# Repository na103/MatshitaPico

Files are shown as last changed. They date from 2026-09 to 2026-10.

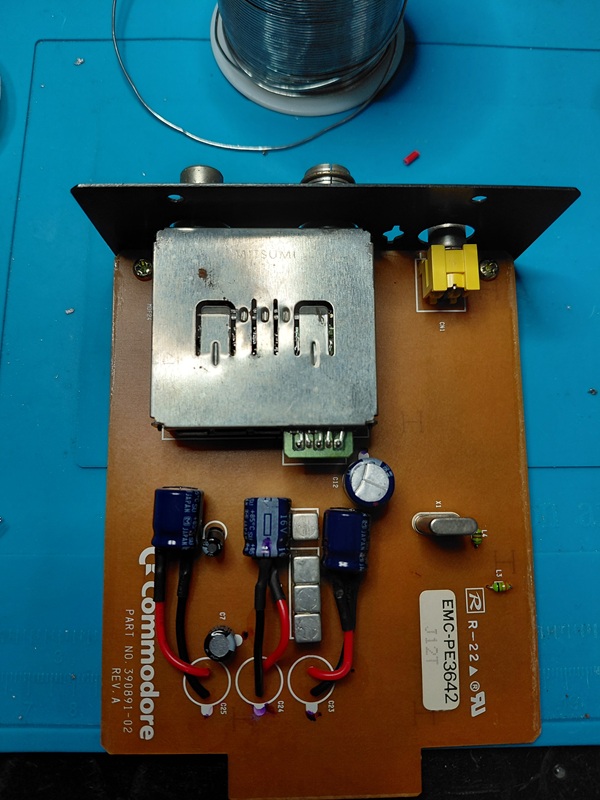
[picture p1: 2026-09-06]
img/beta_assembly/04_beta_assembly.jpg

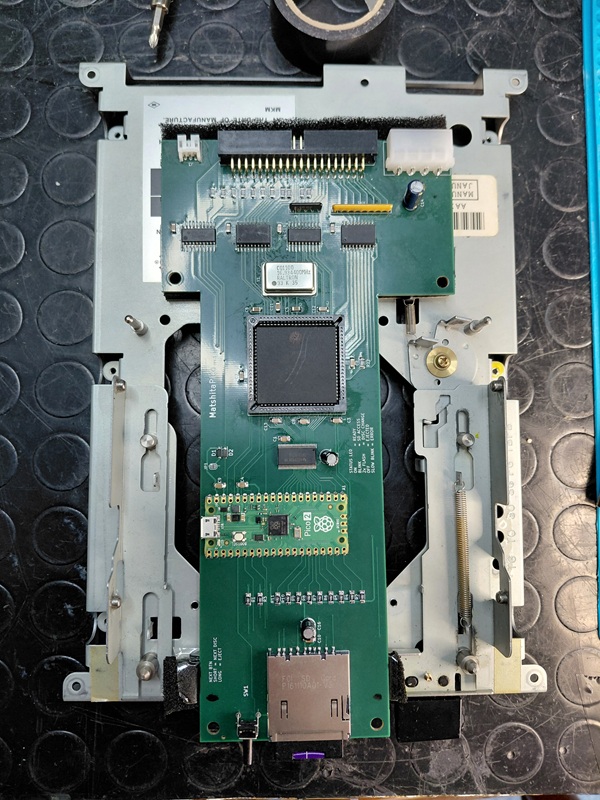
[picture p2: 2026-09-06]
img/beta_assembly/01_beta_assembly.jpg

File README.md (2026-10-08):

<!--
  MatshitaPico — Solid-state CD-ROM drive replacement for the Commodore CDTV
  Copyright (c) 2026 Nicola Avanzi (na103)
  Licensed under Creative Commons Attribution 4.0 International (CC BY 4.0).
  See LICENSE.
-->

# MatshitaPico — a solid-state CD-ROM drive for the Commodore CDTV

**MatshitaPico** is a solid-state replacement for the optical CD-ROM drive of the
**Commodore CDTV**: BIN/CUE disc images stored on a microSD
card take the place of the optical mechanism.

**Why:** many CDTV drives have a worn-out laser and cannot be repaired, and no drop-in
replacement has ever existed. This project keeps these machines alive.

> This repository contains the **CPLD design (HDL)**, **technical documentation**, **RP2350 firmware**, **KiCad hardware project of beta board** and the **Amiga-side `mpdisk.device` + boot CD builder** for hardfiles.
---

## Community beta

Because of the limited turnout in the project's closed beta testing, I have decided to open
MatshitaPico testing up to the whole Amiga community.

The final version should not differ much from this first one, apart from an ATF1508 CPLD in a
TQFP-100 package, programmable in-circuit through a JTAG connector. The key point for the final
version is the **PCB layout**: it must be designed together with a 3D-printed mounting bracket.
The original eject button could also be reused as a control button.

This first version **is** installable — as you can see from the photos [here](https://github.com/na103/MatshitaPico/tree/main/img/beta_assembly) —
but several modifications are needed to fit it. When I laid out the PCB I did not worry about
its dimensions.

## The key insight

The CDTV service manual contains **no schematic for the CD-ROM subsystem**: all of the
CD-ROM electronics (CD-DSP, the Sanyo **LC8951** decoder, the drive's own microcontroller)
live on a PCB **inside the drive mechanism**, not on the motherboard. The motherboard only
carries the *host side* — the **DMAC (U36)**, the **6525/TPI (U32)** and glue logic — which
talks to the drive through connector **CN9** (42 pins, sheet 10 of schematic #252605).

→ **CN9 is the emulation point.** The device plugs into CN9 and pretends to be the entire
drive. The LC8951 does **not** interpret commands (it is a host↔µC FIFO mailbox); the
replacement emulates both the LC8951 host interface and the drive µC command protocol
(the proprietary CDTV/Sony command set).

## Hardware architecture

```
   CDTV (CN9, 5 V TTL)
        |  DB0-7, _HWR/_HRD/_CMD/_STEN/_DTEN/DRQ/_ENABLE/_STCH + RESET
        v
   CPLD  ATF1508AS  (5 V, 128 macrocells, PLCC84, JTAG; socketed, programmed out of circuit)
        |  - real-time 5 V front-end; host-interface FSM (DRQ mode)
        |  - clock division C16M -> BCLK/LRCK; SCOR / subcode generation
        |  <- level shifting 5 V <-> 3.3 V (SN74CBTD16211 bus switch, no DIR, 5 V clamp)
        v
   MCU  RP2350 / Raspberry Pi Pico 2  (3.3 V)
        - drive command protocol - BIN/CUE from SD
        - I2S audio 44.1 kHz (PIO) - subcode Q - UI (NEXT + LED)
   + 16.9344 MHz crystal oscillator (C16M, DIP14 metal-can 5 V TTL)
```

**Key constraint:** the CN9 bus is 5 V TTL and the RP2350 is **not** 5 V-tolerant, so a
native 5 V front-end is required (**ATF1508AS**, the `AS` variant, not `ASV`). The CPLD
performs four things in parallel — master clock, I2S audio, subcode, host DMA — plus command
glue logic; the heavy protocol logic runs on the RP2350.

## What the CPLD does

The CPLD is the only chip that faces CN9 (a pure 5 V domain). It contains:

- **`clkgen`** — derives the audio clocks (`BCLK`, `LRCK`, frame sync) from the `C16M`
  master clock (16.9344 MHz = 384 x 44.1 kHz), so the audio stays phase-coherent with the
  motherboard DAC (Sanyo LC7883M).
- **`host_if`** — the LC8951-style host-interface FSM: it captures host commands (async latch
  on the rising edge of `_HWR`), drives status replies over `_HRD`/`_STEN`, and runs the DMA
  data path in **DRQ mode** (`DRQ` high = byte ready). `EOP` is not on CN9 — the DMAC counts
  it — so ending a sector is just lowering `DRQ`.
- **top level** — subcode generation (`SBCP`/`SCOR`/`EFFK`; `SCCK` is a host **input**) and
  buffering of `DATA`/`EMPHASIS` from the RP2350.

## The golden reference

`cdtv.cpp` from WinUAE (plus `cdtvcr.cpp` for the CDTV-CR variant) is a complete emulation of
the DMAC + 6525 + LC8951 + command protocol. It is the **executable specification** the
firmware is ported from. (The WinUAE sources are not redistributed here — see the WinUAE
project.) The CDTV extended ROM is the real host-side protocol engine.

## Drive command set (summary)

`0x01` seek · `0x02` read · `0x04`/`0x05` motor on/off · `0x09`/`0x0a` play LSN/MSF ·
`0x0b` play track range · `0x82` clear-error · `0x84` mode set · `0x85` mode sense ·
`0x86` capacity · `0x87` subq · `0x8a` read TOC · `0xa2`/`0xa3` front panel.

The full, byte-level command reference — including the vendor `0x6x` hardfile page — is in
[`docs/drive-commands.md`](docs/drive-commands.md).

## Status

The device is functionally complete on real hardware: data boot, persistent disc change,
CD audio (play / pause / skip / stop), CD+G graphics, and the activity LED all work on a real
CDTV. 

## Optional: hardfiles (`mpdisk.device`)

With the firmware built with `ENABLE_MPDISK`, `.hdf` hard-disk images in the root of the SD
card become read/write Amiga units **MPD0..MPD3**, served through the CD controller itself
(no extra hardware). A small boot CD loads `mpdisk.device`, mounts the hardfiles and hands the
system over to MPD0:, so a CDTV can run Workbench from a writable disk. The Amiga sources and
the boot CD builder are in [`amiga/`](amiga) and [`tools/`](tools) — see
[`amiga/README.md`](amiga/README.md).

## Thanks
Thankyou to all the people who have support this project.<br>
Andrea Quagliarini, Mirco Gaggiottini, Carlo Santagostino, Federico Di Dato.

## License

This work is licensed under the **Creative Commons Attribution 4.0 International License
(CC BY 4.0)**. See [`LICENSE`](LICENSE). You are free to share and adapt the material for any
purpose, provided you give appropriate credit.

<br><br>
If you found this my work useful, please consider buying me a cup of coffee if you want:<br>


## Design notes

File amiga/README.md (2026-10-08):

<!--
  MatshitaPico — Solid-state CD-ROM drive replacement for the Commodore CDTV
  Copyright (c) 2026 Nicola Avanzi (na103)
  Licensed under Creative Commons Attribution 4.0 International (CC BY 4.0).
  See LICENSE.
-->

# MatshitaPico — Amiga side: `mpdisk.device` and the boot CD

This directory holds the **Amiga-side sources** of the optional *mpdisk* feature:
read/write **`.hdf` hardfiles** stored on the MatshitaPico microSD and exposed to the
CDTV as block-device units **MPD0..MPD3**. The CDTV can boot from a small CD, mount
the hardfile and hand the system over to it: a CDTV with a writable hard disk, and no
extra hardware beyond the drive replacement.

The firmware half of the feature (vendor commands `0x60`–`0x64`) is compiled in only
with **`ENABLE_MPDISK`** — see [`../firmware/README.md`](../firmware/README.md) and the
byte-level reference in [`../docs/drive-commands.md`](../docs/drive-commands.md).

## How it works

```
   CDTV  (68000, Kickstart 1.3)
     |   mpdisk.device  -- trackdisk-like exec device, units MPD0..MPD3
     |       |  vendor commands on the CD command port (DMAC 0xA1)
     |       |  READ  = DMA (DRQ), like a CD sector read
     |       |  WRITE = bulk bytes on 0xA1, one block per command
     v       v
   CN9 -> CPLD -> RP2350 firmware -> FatFs -> /*.hdf on the SD card
```

There is no extra bus or connector: the device reuses the **CD controller itself**
(DMAC U36 + 6525 U32), found through `expansion.library/FindConfigDev`. The DMAC is
**shared** with the ROM-resident `cdtv.device`, which stays alive, so the pipe:

- catches the per-byte `STEN` replies with its **own INT2 server** at priority 127,
  ahead of `cdtv.device`'s (with a retry if a byte is still stolen);
- **arbitrates the DMA**: before each read chunk it checks, under `Disable()`,
  `cdtv.device`'s "CD DMA in flight" flag (`272(a6)`) and backs off if a CD transfer
  is running; the DMA itself is programmed exactly like the ROM does (`f057f4`),
  with long-word writes to `WTC`/`ACR` (byte writes are not latched by the DMAC);
- paces the 7 command bytes like the ROM does, and writes **one block per WRITE
  command**, using `STATUS` as a per-block handshake (the CPLD FIFO is 2 bytes).

## Layout

```
amiga/
├── mpdisk/                 mpdisk.device
│   ├── device.c            exec framework: romtag, init, vectors, trackdisk commands
│   ├── pipe.c / pipe.h     transport: DMAC/6525 access, STEN capture, arbitrated DMA
│   ├── pipe_stub.c         WinUAE test backend (reads work.hdf as a file, no hardware)
│   ├── mpdisk_dev.h        device base structure
│   └── Makefile            `make` -> mpdisk.device, `make stub` -> mpdisk_stub.device
├── mpmount/                mpmount: mounts MPD0..MPD3 with the geometry from the firmware
│   ├── mpmount.c           TD_GETGEOMETRY -> MakeDosNode/AddDosNode (OFS, KS 1.3 ROM)
│   ├── crt0.S              minimal entry (no utility.library on KS 1.3) + soft 32-bit div
│   └── Makefile
├── boot/
│   ├── startup-sequence    boot CD script: RMTM, mpmount, assigns to MPD0:, run its S/Startup-sequence
│   └── cd-extra/           free overlay: anything here is merged into the boot CD
└── mount/
    └── MPDisk              static Mountlist (reference / WinUAE / manual `Mount MPD0:`)
```

The PC-side tools are in [`../tools`](../tools):

| Tool | Purpose |
|---|---|
| `build-bootcd.sh` | Builds `mpdisk.device` + `mpmount`, then the boot CD (`.bin` + `.cue`). |
| `mkbootcd.py` | The CD builder: ISO9660 + CDTV trademark (or `DOS\0` bootblock) → MODE1/2352 BIN/CUE. |
| `iso2bincue.py` | EDC/ECC engine used by `mkbootcd.py`; also a standalone ISO → BIN/CUE converter. |
| `mkhdf.py` | Creates an empty `.hdf` of a given size and prints the matching Mountlist entry. |

## Build

Requirements: the **m68k-amigaos-gcc** cross compiler (Bebbo's toolchain), and
`python3` with `numpy` for the CD tools.

```sh
make -C amiga/mpdisk          # -> amiga/mpdisk/mpdisk.device
make -C amiga/mpmount         # -> amiga/mpmount/mpmount
```

### Boot CD

The boot CD needs a few **Commodore binaries** (AmigaDOS `C:` commands and the CDTV
trademark file `CDTV.TM`) which are copyrighted and **not** included. They are extracted
once from **your own genuine CDTV disc** (a MODE1/2352 `.bin`) into a git-ignored cache:

```sh
tools/build-bootcd.sh --genuine "/path/to/CDTV_genuine.bin"   # first run: extracts the cache
tools/build-bootcd.sh                                         # later runs: standalone
```

`RMTM`, `LoadWB` and `NewCLI` are not in the `/C` directory of a genuine disc: copy them
by hand into `tools/.bootcd-cache/C/` (`RMTM` from the root of the CDTV Demo Disc,
`LoadWB`/`NewCLI` from Workbench 1.3). `RMTM` must run first, or the CDTV stays on the
splash screen.

The result is `build/mpdisk-bootcd.bin` + `.cue` (or `--out <base>`): copy it into `/games`
on the SD card like any other disc.

## Preparing a hardfile

```sh
python3 tools/mkhdf.py disk0.hdf 64       # empty 64 MB hardfile
```

Copy it into the **root** of the SD card. Units are assigned to the first four `*.hdf` in
name order (`disk0.hdf`..`disk3.hdf` keeps it obvious). Format it as **OFS** (`DOS\0`,
built into the Kickstart 1.3 ROM, so no `L:FastFileSystem` is needed) — in WinUAE, mounted
as a normal hardfile, or on the CDTV. For the boot CD flow, MPD0: must contain a bootable
system (`C`, `L`, `LIBS`, `DEVS`, `S`, ...): it becomes `SYS:` and its
`S/Startup-sequence` is executed.

Use a defragmented card: a contiguous `.hdf` keeps writes away from the FAT.

## Testing in WinUAE

`make -C amiga/mpdisk stub` builds `mpdisk_stub.device`: the same `device.c` with a backend
that reads `work.hdf` as a plain file. Copy it to `DEVS:mpdisk.device`, the Mountlist to
`DEVS:`, then `Mount MPD0:`. The init result is written to `RAM:mpdisk-init.log`. This
validates the device framework without any hardware.

## Limits

- The DMAC is shared with the CD: hardfile and CD access are serialised (`Forbid()` around
  each request), and throughput is about **140 KB/s**.
- Ejecting/changing the CD still reboots the CDTV (that is `cdtv.device`'s behaviour on a
  media change), so the hardfile session ends with it.

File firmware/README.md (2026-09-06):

<!--
  MatshitaPico — Solid-state CD-ROM drive replacement for the Commodore CDTV
  Copyright (c) 2026 Nicola Avanzi (na103)
  Licensed under Creative Commons Attribution 4.0 International (CC BY 4.0).
  See LICENSE.
-->

# MatshitaPico — RP2350 firmware

This directory holds the **application source** of the RP2350 / Raspberry Pi Pico 2
firmware: the drive command protocol, BIN/CUE image handling, I2S audio, the subcode
Q / CD+G channel, and the UI (NEXT button + status LED). The CPLD design that pairs
with it (the real-time 5 V front-end on CN9) is in [`../hdl`](../hdl); the protocol
itself is documented in [`../docs`](../docs).

> This is a **read-only reference copy** of the core sources. The build system
> (`CMakeLists.txt`), the SD-card driver glue (SPI-over-PIO transport and
> `hw_config`), and the third-party FatFs library are maintained with the full
> firmware tree and are **not** included here — see *Dependencies* below.

## What runs where

```
   CDTV (CN9, 5 V TTL)
        |
        v
   CPLD  ATF1508AS   real-time front-end: host-interface FSM (DRQ mode),
        |            audio clock division (C16M -> BCLK/LRCK), subcode burst
        v            engine (SBCP/SCOR/EFFK), /INAC activity LED
   MCU  RP2350       THIS firmware: drive command protocol, SD (BIN/CUE),
                     I2S audio samples, subcode Q stream, NEXT + LED
```

The RP2350 is **not** 5 V-tolerant, so it never touches CN9 directly: the CPLD is the
only chip in the 5 V domain, and a bus switch level-shifts the CPLD↔Pico signals. The
firmware talks to the CPLD through the register/handshake contract in
[`../hdl/host_if.v`](../hdl/host_if.v) (see `src/host_link.h`).

## SD card layout

The firmware reads a FAT-formatted microSD with this layout:

```
/                 <- SD root
├── games/        <- CD-ROM images
│   ├── Game A.cue
│   ├── Game A.bin
│   ├── Game A.sub     (optional: CloneCD subchannel, enables CD+G)
│   ├── Game A.subok   (optional: empty marker, forces subcode ON for a mixed disc)
│   └── ...
├── work.hdf      <- hardfiles in the root (ENABLE_MPDISK builds only)
└── extra.hdf
```

* **CD images — `/games/*.cue`.** Discs live in the `/games/` folder as **BIN/CUE, 2352-byte
  raw** sectors (not `.iso`: an ISO is 2048-byte data only and carries no audio, sync or EDC).
  The `.cue` and its referenced `.bin` sit side by side; the NEXT button cycles through them in
  name order. A companion `.sub` (CloneCD subchannel) next to a `.cue` enables **CD+G** playback,
  and an empty `.subok` marker forces the subcode stream on for a mixed disc known to be safe.
* **Hardfiles — `*.hdf` in the root** (only when built with **`ENABLE_MPDISK`**). Amiga hard-disk
  images placed in the SD root are exposed as block-device units **MPD0..MPD3** (first four found,
  in name order). These are ordinary **`.hdf` files, interchangeable with WinUAE** — mount the same
  image in WinUAE to prepare or inspect it, then drop it in the SD root. See *Optional feature:
  mpdisk hardfiles* below.

## The golden reference

The command protocol is a port of `cdtv.cpp` from **WinUAE** (the executable
specification of the DMAC + 6525 + LC8951 + command set). The WinUAE sources are not
redistributed here. See [`../docs/drive-commands.md`](../docs/drive-commands.md) and
[`../docs/protocol-cdtv.md`](../docs/protocol-cdtv.md).

## Source layout

| File | Role |
|---|---|
| `main.cpp` | main loop: command intake, status/data replies, STCH announce, auto-insert |
| `cdtv_drive.{h,cpp}` | drive state machine + command dispatch (ported from `cdtv.cpp`) |
| `host_link.{h,cpp}` | link layer to the CPLD (IRQ capture, bus gather/scatter, handshakes) |
| `cd_image.{h,cpp}` | CD image (BIN/CUE 2352 raw): TOC, LSN→offset, prewarm, subcode gate |
| `cue_parser.{h,cpp}` | SDK-free CUE sheet parser (unit-testable on the PC) |
| `storage.{h,cpp}` | SD/FatFs glue: image scan, cached reads (data / audio / subcode) |
| `audio.{h,cpp}` | I2S-slave transmitter on A_DATA, ping-pong DMA |
| `subcode.{h,cpp}` | subcode Q + CD+G R-W stream on A_SUBQ |
| `subq_packet.h` / `subpw_block.h` | Red Book Q packet + P..W wire block builders |
| `cdrom_util.h` | LSN/MSF/BCD conversions |
| `ui.{h,cpp}` / `ui_logic.h` | NEXT button + status LED (pure logic split out for tests) |
| `pinmap.h` | RP2350 GPIO assignment (matches the routed PCB) |
| `ram_func.h` | portable macro to place critical-path code in RAM (removes XIP stalls) |
| `pio/*.pio` | PIO programs: I2S slave, subcode serialiser, SD SPI master |

Files that are compiled for both the device and the PC unit tests (`cd_image`,
`cue_parser`, `storage`, `subq_packet`, `subpw_block`, `ui_logic`) avoid the Pico SDK
in their hot paths; `ram_func.h`'s `RAM_FUNC` macro is a no-op off ARM so the shared
sources compile identically on the host.

## Dependencies (not included here)

* **Pico SDK** — the RP2350 platform (`pico/stdlib.h`, `hardware/*`, PIO tooling).
* **FatFs** (ChaN's ff15, e.g. via `no-OS-FatFS-SD-SPI-RPi-Pico`) — the FAT filesystem
  behind `storage.cpp`. Only the standard `f_*` API is used, so any FatFs port works.
* **SD driver glue** — the SPI-over-PIO transport (`sd_spi_pio`) and `hw_config` that
  bind FatFs to the rev.0 PCB pins (`pinmap.h`). The rev.0 SD pins do not map to any
  RP2350 hardware SPI, so the bus is bit-banged in PIO on `pio2`.

## Optional feature: mpdisk hardfiles

Read/write `.hdf` hard-disk images (an Amiga block device, `mpdisk.device`) are gated
behind the compile-time flag **`ENABLE_MPDISK`** (default **off**). With the flag off
the vendor pipe (commands `0x60`–`0x64`) compiles out entirely and the firmware is the
plain CD-ROM replacement; with it on, `.hdf` files in the SD root become units
MPD0..MPD3. See the `#if ENABLE_MPDISK` blocks in `cdtv_drive.cpp` / `storage.cpp` and
[`../docs/drive-commands.md`](../docs/drive-commands.md).

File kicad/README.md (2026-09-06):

## Bill of materials
| Qt. | Description | Designator | Part code | Note |
|:---:|---|---|---|---|
|4 |Res 10K |R1-R3,R22 |RC1206FR-0710KL
|6 |Res 100R |R15,R17-R21 |RC1206FR-07100RL | |
|8 |Res 47K |R4-R11 |RC1206FR-0747KL | |
|2 |Res 470R |R12, R13 |RC1206FR-07470RL | |
|2 |Res 1K |R14,R16 |RC1206FR-071KL | |
|1 |Res 0R |R23 |RC1206FR-070RL | |
|1 |Bus Array 8RES 2.2K |RN1 |4609X-101-222LF | |
|1 |Bus Array 4RES 1K |RN2 |4605X-101-102LF | |
|17 |Cap 100nF |C1-C13,C17-C20 |C1206C104K5RACTU | |
|2 |Cap 10uF |C15,C16 |EEA-GA1V100H | |
|1 |Cap 47uF |C14 |EEU-FC1V470H | |
|1 |DIODE SCHOTTKY |D1 |MBR120ESFT3G | |
|1 |DIODE SCHOTTKY |D2 |BAT54W-E3-08 | |
|1 |BUS SWITCH |U2 |SN74CBTD16211DGGR | |
|1 |CPLD ATF1508 |U1 |ATF1508AS-10JU84 | from ebay or utsource.net |
|1 |OSC DIP 16.9344MHZ  |Y1 |NA | from aliexpress | 
|1 |74LS245 |U3 |SN74LS245DWR | |
|2 |74LS244 |U4,U6 |SN74LS244DWR | |
|1 |74LS541 |U5 |SN74LS541DWR | | 
|1 |SOCKET PLCC 84POS |U1 |940-44-084-24-000000| |
|1 |PI PICO 2 RP2350 |A1 |SC1631 | |
|1 |CONN 4POS 5.08MM |J1 |641737-1 | |
|1 |CONN 40POS 2.54MM |J2 |61204021721 | |
|1 |CONN 3POS 2MM |J3 |S3B-PH-K-S | |
|1 |CONN SD CARD SMD |SD1 |10067847-011RLF | |
|1 |SWITCH SPST-NO |SW1 |2-1825027-0 | |

## Note ##
The ATF150x programmer needed to program the CPLD can be found [here](https://github.com/roscopeco/atfprog-hardware).

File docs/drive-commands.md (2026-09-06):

<!--
  MatshitaPico -- Solid-state CD-ROM drive replacement for the Commodore CDTV
  Copyright (c) 2026 Nicola Avanzi (na103)
  Licensed under Creative Commons Attribution 4.0 International (CC BY 4.0).
  See LICENSE.
-->

# Command set handled by the firmware — reference

> Reference for the commands that the RP2350 firmware recognizes and serves on CN9. It is
> the **specification of what is implemented on real hardware**, complementary to
> [`protocol-cdtv.md`](protocol-cdtv.md) (which derives from WinUAE's `cdtv.cpp`).

## Framing and reply channels

- **Command** = bytes written by the host to `base+0xA1` (the DMAC command register),
  captured by the CPLD as an asynchronous latch on the **rising edge of `_HWR`** and passed
  to the firmware.
- **Command length** (`cmd_length()`): depends on the opcode. Most are **7 bytes** (opcode
  + 6 parameters); some status/polls are **1 byte**; the `0x80` ping is **2 bytes**; the
  `0x00` filler is **1 byte**. An incomplete command older than 10 ms is discarded (parser
  resync).
- **Reply** over three distinct channels:
  - **STEN** (mailbox): short replies read by the host via `0xA1`, **1 `_STEN` pulse per
    byte** (long pulse ~118 µs). E.g. status, capacity, subq, TOC, vendor DETECT/GEOMETRY/
    STATUS.
  - **DMA / DRQ**: the data stream (CD sectors or hardfile blocks) transferred via hardware
    DMA (`DRQ`↑ = byte ready). E.g. `0x02` read CD, `0x62` read hardfile.
  - **STCH** (asynchronous notification): events (seek/play done, media change) — not a
    byte reply but a pulse that makes the host CD task react.
- A command with no reply (`0x00`, seek, motor…) does **not** assert `_STEN`.

Byte-order/handshake details are in [`timing-host-interface.md`](timing-host-interface.md)
and [`protocol-cdtv.md`](protocol-cdtv.md).

---

## CD protocol commands (port of WinUAE's `cdtv.cpp`)

| Op | Name | Len | Payload | Reply | Description |
|----|---|-----|---|---|---|
| `0x00` | NOP / filler | 1 | — | none | Trailing byte of the "armed poll" `f058ea` (buffer `81 00`). Does not assert `_STEN`, does not misalign the parser. If treated as a 2-byte command it "ate" the next opcode. |
| `0x80` | test / ping | 2 | — | STEN 2B `AA 55` | Test command. |
| `0x01` | seek | 7 | LSN | STCH | Seek to the position. Marks `finished` and pulses STCH (no data). |
| `0x02` | read data | 7 | LSN(3) + n_sectors(2) | DMA n×sector_size | Starts the DMA transfer of the data sectors. Guard: out of range / no media → error, no phantom DMA. `sector_size` from the `0x84` mode-set. |
| `0x04` | motor on | 7 | — | — | Turns the motor on (`finished`). |
| `0x05` | motor off | 7 | — | — | Turns the motor off (`finished`). |
| `0x09` | play (LSN) | 7 | start(3) + len(3) | STCH | Starts audio playback from `start` for `len` frames. `00…00 / 00…00` = **stop**. STCH at start (statusfunc). |
| `0x0a` | play (MSF) | 7 | start(3) + end(3) | STCH | Like `0x09` but parameters in MSF (converted to LSN). |
| `0x0b` | play track range | 7 | track_start(1) + track_end(1) | STCH | Plays from track `start` to `end`. `00 00` = play from the current position to the end of disc (a ROM quirk of the CD+G screen). |
| `0x81` | status | 1 | — | STEN 1B | Status byte: b0=1 (always), b2=playing, b3=finished, b4=error, b5=motor, b6=media. This is the host's main poll. |
| `0x82` | read/clear error | 7 | — | STEN 6B | Returns the error state (b4 of `r[2]` if error) and **clears** `error`/`ready`. |
| `0x83` | inquiry | 7 | — | STEN 12B | Identification string `"MATSHITA0.96"`. Not a gate (the ROM does not validate it). |
| `0x84` | mode set | 7 | page(1) + size(2) + … | — | Sets the **sector size** (512/1024/2048/2052/2336/2340); an invalid size → error. Typical init `84 02 08 00 00 0F 00` (2048). |
| `0x85` | mode sense | 1 | — | STEN 2B | Returns the current sector size. |
| `0x86` | capacity | 1 | — | STEN 5B | `last_lsn-1` (24 bit) + sector size (16 bit). |
| `0x87` | subq | 7 | MSF/LSN flag in bit1 | STEN 13B | Q position channel: audio_status, ADR/control, track, index, absolute position (disc) and relative (track). MSF or LSN per `cmd[1]&2`. Used by the audio player and (on real hardware) by Sherlock. |
| `0x88` | — | 1 | — | STEN 14B (zeros) | Placeholder (14 zero bytes); a command rarely used by the ROM. |
| `0x89` | disc info | 7 | — | STEN 5B | `first_track`, `last_track`, MSF of `last_lsn`. |
| `0x8a` | read TOC | 7 | MSF/LSN flag + point(1) | STEN 8B | TOC record for track `point`. **Marks "mounted"** (`toc_read`) → the boot-time STCH announce stops. |
| `0x8b` | pause / resume | 7 | 0x00=pause / else=resume | — | Pauses/resumes playback (`audio::pause`). While paused `playing` stays set (like the reference). |
| `0xa2` | front panel | 1 | — | STEN 4B (zeros) | Front panel (placeholder). |
| `0xa3` | front panel enable | 7 | — | — | Enables the front panel (`finished`). Part of the CD+G sequence (`04, 0B, A3`). |
| *default* | unknown | 7 | — | — | Any other opcode → `error`. |

**Status byte (`0x81`)** — bits: `0x01`=ready-inverted (always 1), `0x04`=playing,
`0x08`=finished, `0x10`=error, `0x20`=motor, `0x40`=media. Ejected = `0x01`, with media =
`0x41`, at end of spin-up = `0x49`.

---

## Vendor mpdisk commands — `.hdf` hardfile (`0x60`–`0x64`)

Vendor page for the **hardfile** subsystem (`mpdisk.device` ↔ firmware). All 7 bytes:
`op, unit, LBA[4 MSB-first], count`. `unit` = 0..3 (MPD0..MPD3 = disk0.hdf..disk3.hdf);
block = 512 B. Exclusive with the CD in v1 (the Amiga device uses `Forbid()`).

| Op | Name | Payload | Reply | Description |
|----|---|---|---|---|
| `0x60` | DETECT | — | STEN 8B | Signature `"MPDK"` + version (`0x01`) + unit count + block size (512). Re-runs `scan_hardfiles()` of the SD root before replying (robust against boot-time ready delays). It is the gate that tells the device "the mpdisk firmware is present". |
| `0x61` | WRITE | unit, LBA, count | bulk-rx | Enters **bulk-rx**: after the command, `count×512` data bytes follow via `_HWR`, accumulated per block and written to the `.hdf`. The device writes **1 block per command** (waiting for STATUS acts as the handshake → no overflow of the CPLD's 2-byte FIFO). Outcome via `0x63`. |
| `0x62` | READ | unit, LBA, count | DMA count×512B | Reads `count` blocks from the `.hdf` and transfers them via DMA (DRQ). Range-checked (missing unit / LBA past capacity → error, no phantom DMA). |
| `0x63` | STATUS | — | STEN 2B | Flags: b0=ready (pipe active), b1=last error (`error` or a write error), b2=bulk-rx write in progress. Second byte = 0. Used after WRITE to confirm the outcome. |
| `0x64` | GEOMETRY | unit | STEN 6B | Geometry of the unit: total_blocks (4 bytes) + block size (2 bytes, 512). Missing `unit` → total_blocks=0 + error. The device derives HighCyl = TotalSectors/32-1 (self-describing: changing the size of a `.hdf` does not require rebuilding the CD). |

### Free / reserved opcodes
- `0x65`, `0x66`–`0x6F` are **free** (the dispatch treats them as "unknown" → `error`).

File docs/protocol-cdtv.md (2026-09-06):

<!--
  MatshitaPico -- Solid-state CD-ROM drive replacement for the Commodore CDTV
  Copyright (c) 2026 Nicola Avanzi (na103)
  Licensed under Creative Commons Attribution 4.0 International (CC BY 4.0).
  See LICENSE.
-->

# CDTV CD-ROM drive protocol specification

Extracted from WinUAE's `cdtv.cpp` (WinUAE emulation by Toni Wilen, technical info by
Mark Knibbs) and `include/blkdev.h`. This is the behavior the replacement device must
reproduce on the drive side, exposed on connector **CN9**.

> Convention: "host" = the CDTV (68000 CPU + DMAC + 6525). "drive" = the device we are
> building. Numbers are hexadecimal when prefixed with `0x`.

---

## 1. General model

The CDTV never talks directly to the optics: it talks to a **drive microcontroller**
through the **LC8951** decoder, which acts as a mailbox (command FIFO + status register)
and as a data-transfer engine. The replacement device must emulate **both** the LC8951
host-interface hardware **and** the drive µC logic.

Five logical channels coexist on CN9:

| Channel | Direction | CN9 signals | Function |
|---|---|---|---|
| Command | host→drive | `DB0-7`, `HWR`, `CMD` | command bytes into the FIFO |
| Status | drive→host | `DB0-7`, `HRD`, `STEN` | command reply bytes |
| Notify | drive→host | `STCH` | asynchronous status change (IRQ) |
| Data | drive→host | `DB0-7`, `DRQ`+`HRD` (measured: `DTEN`/`XAEN` never asserted) | sectors over DMA |
| Subcode | drive→host | `SCOR`, `SBCP`, `SCCK` | subchannel frames (Q channel etc.) |
| Audio | drive→host | `C16M`, `DATA`, `LRCK`, `BCLK` | digital I²S audio + clocks |
| Control | host→drive | (serial via a 6525 port) | volume / DAC format |

On the CDTV side these signals are driven/read by the **6525 (TPI)** and the **DMAC**;
for us the semantics matter, not those chips (they live on the motherboard).

---

## 2. Command sequence (command/status handshake)

1. The host writes the command bytes one at a time with `CMD` asserted (`HWR`).
   The first byte is the **opcode**; the total length depends on the opcode (see §3).
2. When the drive has received all the expected bytes, it executes the command and
   produces 0 to N bytes of **output** (command status).
3. The drive signals the availability of the output: `STEN` active while there are bytes
   to read. (In `cdtv.cpp`: at command completion `sten=1, stch=0`.)
4. The host reads the output bytes one at a time (`HRD`, register at `0xa1`). After the
   last byte `STEN` goes inactive (`sten=0`).
5. Asynchronous events (end of seek, end of audio, media change, error, motor) are
   notified by raising **`STCH`** (`do_stch`), which generates an IRQ (INT2) on the CDTV.

Important rules:
- A command with no output (`size=0`) still completes the cycle: the host understands
  this because `STEN` does not activate (or deactivates immediately).
- `STCH` is raised only if enabled by the 6525 configuration (`tp_cr & 1` and the mask,
  see §9). In the initial reset `stch=1`.

---

## 3. Command set

Legend: **Len in** = number of command bytes (opcode included). **Out** = reply bytes.
`s[n]` = the n-th command byte.

| Op | Name | Len in | Output | Notes |
|----|---|:---:|---|---|
| `0x00` / `0x80` | Test / ping | 2 | `0xAA 0x55` | presence handshake |
| `0x01` | **Seek** | 7 | — | LBA in `s[1..3]`; raises `STCH` at end of seek; `cd_finished=1` |
| `0x02` | **Read (data)** | 7 | — | start LSN=`s[1..3]`, sector count=`s[4..5]`; starts the DMA transfer (§5) |
| `0x04` | Motor on | 7 | — | `cd_motor=1`, `cd_finished=1` |
| `0x05` | Motor off | 7 | — | `cd_motor=0`, `cd_finished=1` |
| `0x09` | **Play audio (LSN)** | 7 | — | start=`s[1..3]`, *length*=`s[4..6]` (end=start+len) |
| `0x0a` | **Play audio (MSF)** | 7 | — | start=`s[1..3]`, end=`s[4..6]` in MSF |
| `0x0b` | Play track range | 7 | — | track_start=`s[1]`, idx_start=`s[2]`, track_end=`s[3]`, idx_end=`s[4]` |
| `0x81` | **Status byte** | 1 | 1 | status bitmask (see §4) |
| `0x82` | Read/clear error | 7 | 6 | if `cd_error` sets bit4 of out[2]; clears `cd_error`, `cd_isready` |
| `0x83` | **Inquiry** (model) | 7 | 12 | string **`MATSHITA0.96`** |
| `0x84` | **Mode set** | 7 | — | sector size = `s[2..3]` (see §5) |
| `0x85` | Mode sense | 1 | 2 | current sector size (16 bit, MSB first) |
| `0x86` | **Capacity** | 1 | 5 | lastaddress-1 (3B) + sector size (2B); `cd_error` if no media |
| `0x87` | **SubQ** (position) | 7 | 13 | `s[1]&2` ⇒ MSF, else LSN (see §6) |
| `0x88` | (disc info?) | 1 | 14 | 14 zero bytes (placeholder) |
| `0x89` | Disc info | 7 | 5 | first_track, last_track, size MSF (3B) |
| `0x8a` | **Read TOC** | 7 | 8 | track=`s[2]`, `s[1]&2`⇒MSF (see §7) |
| `0x8b` | Pause/Resume | 7 | — | `s[1]==0x00` ⇒ pause, else resume |
| `0xa2` | (?) | 1 | 4 | 4 zero bytes |
| `0xa3` | Front panel enable | 7 | — | enable/disable the front panel (`s[1]`) |
| others | unknown | — | 0 | sets `cd_error` |

> The 7-byte commands have 6 payload bytes after the opcode; often only some are used.
> The length is the discriminant by which the drive knows the command is complete.

---

## 4. Status byte (command `0x81`)

A single byte, active bits = condition true:

| Bit | Value | Meaning |
|-----|---|---|
| 0 | `0x01` | NOT ready (`!cd_isready`) |
| 2 | `0x04` | audio playing (`cd_playing`) |
| 3 | `0x08` | operation finished (`cd_finished`) |
| 4 | `0x10` | error (`cd_error`) |
| 5 | `0x20` | motor on (`cd_motor`) |
| 6 | `0x40` | media present (`cd_media`) |

Reading command `0x81` clears `cd_finished`.

### Audio states (`cd_audio_status`, from `blkdev.h`)
Used in SubQ and in notifications:

| Constant | Value |
|---|---|
| NOT_SUPPORTED (data) | `0x00` |
| IN_PROGRESS (play) | `0x11` |
| PAUSED | `0x12` |
| PLAY_COMPLETE | `0x13` |
| PLAY_ERROR | `0x14` |
| NO_STATUS | `0x15` |

---

## 5. Data transfer (sector read)

1. The host sets the **sector size** with `0x84` (mode set). Valid values:
   `512, 1024, 2048, 2052, 2336, 2340`. Typical data CD-ROM = **2048**.
2. The host sends `0x02` (read) with the start LSN and sector count.
3. On the CDTV side the DMAC is programmed (destination address ACR, word count WTC) and
   started; the drive delivers the sector bytes on the data bus with the
   `DTEN`/`DRQ`/`HRD` handshake.
4. The transfer is in **16-bit words**: the DMAC fetches 2 bytes per cycle
   (`dma_put_byte` ×2). Total bytes to supply = `n_sectors × sector_size`.
5. At the end of the transfer: `cd_finished=1`; on the host side the end-of-DMA IRQ fires.

Size→sector-source mapping (from `dma_do_thread`):
- `2048` → standard data sector (Mode 1 / Mode 2 Form 1 user data).
- `2336/2340/2352/2052` → raw read (needs header/subheader/EDC/ECC from the file).
- `<2048` → a fraction of the sector.

> Implication for the replacement: from the file on the SD card (ISO 2048 or BIN/CUE 2352)
> the requested size must be reconstructed. Having **2352 raw** images is the safest choice
> because it covers all raw requests and the subset can always be extracted.

---

## 6. SubQ — current position (command `0x87`, 13-byte output)

`s[1] & 2` selects the time format: **MSF** if set, **LSN** otherwise.

| Byte | Contents |
|---|---|
| 0 | `cd_audio_status` (§4) |
| 1 | CONTROL/ADR (swapped nibbles: `(x>>4)|(x<<4)`) |
| 2 | track number (BCD→bin) |
| 3 | index (BCD→bin) |
| 4 | 0 |
| 5..7 | **absolute disc** position (MSF or LSN), MSB first |
| 8 | 0 |
| 9..11 | **track-relative** position (MSF or LSN), MSB first |
| 12 | 0 |

The source data comes from `cdrom_qcode` (the subcode Q channel, in BCD). The device must
keep the current position consistent with the audio being played.

---

## 7. TOC, capacity, disc info

**Read TOC** (`0x8a`, out 8 bytes) for the requested track/point:
| Byte | Contents |
|---|---|
| 0 | 0 |
| 1 | `(ADR<<4) | CONTROL` |
| 2 | point (track number) |
| 3 | total number of tracks |
| 4 | 0 |
| 5..7 | start address (MSF or LSN) |

**Capacity** (`0x86`, out 5 bytes): `lastaddress-1` (3B) + sector size (2B).

**Disc info** (`0x89`, out 5 bytes): first_track, last_track, total size in MSF (3B).

The device must build a TOC from the files on SD (from CUE, or from an implicit TOC for a
single ISO). `datatrack` is set if the first track is data (control & 0x0c == 0x04).

---

## 8. CD audio and volume control

- The drive generates `C16M` (16.9344 MHz) and the digital audio stream (`DATA`/`LRCK`/
  `BCLK`, I²S-like format 44.1 kHz 16-bit stereo) that feeds the LC7883 DAC on the
  motherboard.
- During play (`0x09/0x0a/0x0b`) the device plays the audio tracks from the file (BIN/CUE),
  synchronizing position and subcode.
- **Volume**: the host sends it **serially** through port B of the 6525:
  - bit 6 = shift clock; on each edge bit 5 is shifted into `dac_control_data_format`
    (12 bits total). bit 7 = latch strobe: at the latch `cd_volume =
    dac_control_data_format & 0x3FF` (10 bits).
  - The device must capture this serial word and apply the attenuation to the audio output.
    (`xaen`, `enable`, `cmd`, `dten` come from the other port B bits — see the direction
    note in §11.)

---

## 9. Serial subcode (SCOR / SBCP / SCCK)

The drive sends the subchannel frames serially; the CDTV shifts them in through port A of
the 6525.
- `SCOR` = start of subchannel frame (sync). `SBCP` = subchannel byte ready.
- A frame = **`SUB_CHANNEL_SIZE` = 96 bytes** (channels P–W de-interlaced, 12×8).
- The bytes read from port A are **bit-reversed** (see `tp_bget` case 0: each bit is
  mirrored) → the device must emit the bits in the expected order.
- Rate: in `cdtv.cpp` one frame every ~`maxvpos*vblank/75` (≈ 75 frames/s, the CD rate),
  with micro-timing `SUBCODE_CYCLES=460` between bytes. When the motor runs but no playback
  is in progress, periodic `SCOR` pulses are still generated ("frame interrupt").

The status lines toward the CDTV (port C of the 6525, **active low**):
`SBCP` (bit0), `SCOR` (bit1), `STCH` (bit2), `STEN` (bit3/4).

---

## 10. Address conversions

- **LSN/LBA ↔ MSF**: `msf2lsn`, `lsn2msf`. MSF = Minute:Second:Frame, 75 frames/s, with an
  offset of 150 frames (2 s) for the pre-gap. BCD is used in the Q channel (`frombcd`,
  `fromlongbcd`).
- `last_cd_position` = `toc.lastaddress` (end of disc in LSN).

---

## 11. Signal-direction notes — RECONCILED ON REAL HARDWARE

In `cdtv.cpp`, `cmd`, `enable`, `xaen`, `dten` are derived from **port B** written by the
CPU (host→drive), while the LC8951 datasheet gives `DTEN`/`STEN`/`WAIT`(`DRQ`)/`EOP` as
chip **outputs**. Bus captures closed the question:
- Measured directions (continuity + captures): `_CMD`/`_ENABLE`/`_XAEN`/`_DTEN` = drive
  **inputs** (from the TPI U32, port B); `_STEN`/`DRQ`/`_STCH` = drive **outputs**.
- **Polarity**: `_HWR`/`_HRD`/`_CMD`/`_ENABLE`/`_STEN` active-low; **`DRQ` ACTIVE HIGH**;
  `RESET` idle-high.
- **`_DTEN` and `_XAEN` are NEVER asserted** by the CDTV, not even during continuous data
  transfer: the data path uses **only `DRQ`+`_HRD`**, the data phase is distinguished by
  `_CMD` high alone. `EOP` is not on CN9 (the DMAC counts it).
- `cdtv.cpp` models the *register/protocol-level semantics* (correct); the real electrical
  behavior is the measured one, applied to `hdl/host_if.v`.

> Note: further reverse-engineering of the original drive PCB showed that `_XAEN` and
> `_DTEN` are actually drive **outputs** (read by the 6525), and `SCCK` is a drive
> **input** generated by the motherboard. This does not change the measured "never
> asserted / DRQ-only" data path above; see the pinout notes and the HDL comments.

---

## 12. Appendix — CDTV-side register map (reference)

These are the registers **of the CDTV motherboard** (DMAC + 6525), as seen by the 68000.
We do not implement them (they live on the CDTV), but they clarify the semantics.

DMAC (offset from the Zorro II autoconfig base):
| Offset | R/W | Function |
|---|---|---|
| `0x00-0x3F` | R | autoconfig ROM (`dmacmemory`) |
| `0x41` | R | ISTR (interrupt status) |
| `0x43` | R/W | CNTR (control); bits `PREST`=reset, `PDMD`=scsi-dma, `INTEN`, `TCEN`, `DDIR` |
| `0x80-0x83` | W | WTC — word transfer count (32 bit) |
| `0x84-0x87` | W | ACR — address count register (DMA destination) |
| `0x8E-0x8F` | W | DAWR |
| `0xA1` | R/W | **W = command byte to the drive; R = status byte from the drive** |
| `0xB0-0xBF` | R/W | **6525 (TPI)**, register = `(offset-0xB0)/2` (ports A,B,C,dir,etc.) |
| `0xE0/E1` | W | start DMA |
| `0xE2/E3` | W | stop DMA |
| `0xE4/E5` | W | clear ISTR |

6525 (TPI), registers 0–7: 0=port A (subcode in), 1=port B (control→drive + serial
volume), 2=port C (status lines SBCP/SCOR/STCH/STEN), 3/4=dir A/B, 5=dir C / interrupt
mask, 6=control (bit0 = MC, enables interrupt mode), 7=AIR.

ISTR bits: `INT_P`(0x10), `E_INT`(0x20) used for the end-of-DMA IRQ when
`CNTR_INTEN|CNTR_TCEN` are active.

---

## 13. Firmware checklist (what the device must do)

- [ ] Receive/assemble commands (variable length per opcode) — §2/§3.
- [ ] Reply with the output bytes handling `STEN` — §2.
- [ ] Maintain the status flags (ready/playing/finished/error/motor/media) — §4.
- [ ] Generate `STCH` on asynchronous events — §2/§9.
- [ ] Mode set/sense and sector-size reconstruction from the file — §5.
- [ ] DMA sector transfer (data handshake, 16-bit) — §5.
- [ ] TOC / capacity / disc info from CUE/ISO — §7.
- [ ] SubQ with a consistent position in BCD/MSF/LSN — §6.
- [ ] I²S audio 44.1 kHz + `C16M` + serial volume capture — §8.
- [ ] 96-byte/frame subcode generation with bit-reversal and timing — §9.
- [ ] Reply `MATSHITA0.96` to the `0x83` inquiry — §3.

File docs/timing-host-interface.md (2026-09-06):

<!--
  MatshitaPico -- Solid-state CD-ROM drive replacement for the Commodore CDTV
  Copyright (c) 2026 Nicola Avanzi (na103)
  Licensed under Creative Commons Attribution 4.0 International (CC BY 4.0).
  See LICENSE.
-->

# LC8950/LC8951 host-interface timing (datasheet Appendix F)

Derived from the Sanyo LC8950/LC8951 datasheet, Appendix F / TABLE 12 (AC Electrical
Characteristics) and Figures 38–42. These are the timing constraints that the **replacement
device's front-end must meet on CN9** toward the CDTV (the host side of the LC8951). The
LC8950 and LC8951 have **identical** values for these parameters.

> **Fundamental constant: `T` = the XTALCK clock period.**
> In the CDTV, XTALCK ≈ **16.9344 MHz** ⇒ **T ≈ 59.05 ns**.
> Many times are expressed as multiples of T.
>
> Handy values: 2T≈118 ns · 4T≈236 ns · 6T≈354 ns · 8T≈472 ns · 10T≈590 ns.

All values in **ns** unless noted. "—" = not specified.

---

## 1. Command write — host→drive (Figure 38)

Sequence: the host asserts `ENABLE`, sets `CMD` (0 = command/status), places the byte on
`HD0-7`, pulses `HWR`. The drive takes it in and updates `DTEN`/`STEN`.

| # | Parameter | min | max |
|---|---|----:|----:|
| 1 | `ENABLE` active → `HWR` (setup) | 30 | — |
| 2 | `CMD` → `HWR` (setup) | 15 | — |
| 3 | `HWR` low (pulse width) | 50 | — |
| 4 | `HWR` → `DTEN` change | — | 105 |
| 5 | `HWR` → `STEN` change | — | 105 |
| 6 | data `HD0-7` → `HWR` (setup) | 50 | — |
| 7 | `HWR` inactive → data end (data hold) | 20 | — |
| 8 | `HWR` inactive → `ENABLE` inactive | 0 | — |
| 9 | `HWR` inactive → `CMD` inactive | 5 | — |
| 10 | data `HD0-7` → `HWR` inactive (hold) | 0 | — |

→ **Our side (drive)**: we must *sample* `HD0-7` on the `HWR` edge (data stable from ≥50 ns
before, hold ~0 ns) and produce the `DTEN`/`STEN` transition within **105 ns**. All times
easily handled by a CPLD.

---

## 2. Data read — drive→host (Figure 39 = WAIT, Figure 40 = DRQ)

`SELDRQ` selects the mode:
- **DRQ** (Figure 40): `WAIT`/`DRQ` acts as a *data request*. Flow:
  `ENABLE`↓ → `CMD`=1 (data read) → `DTEN`↓ (data ready) → `DRQ`↓ (request) →
  the host pulses `HRD` for each byte, the drive drives `HD0-7` → `EOP`↓ on the last byte.
- **WAIT** (Figure 39): software transfer; the drive raises `WAIT` if the host reads too
  fast, the host waits for `WAIT` to go high again.

### Parameters (Figure 39/40)

| # | Parameter | min | max |
|---|---|----:|----:|
| 31 | `HRD` active → `DTEN` inactive | — | 120 |
| 32 | `HRD` → `EOP` (setup) | — | 120 |
| 33 | `HRD` inactive → `ENABLE` inactive | 0 | — |
| 34 | `HRD` inactive → `CMD` active | 5 | — |
| 35 | `HRD` inactive → `EOP` inactive | — | 120 |
| 36 | `CMD` active → `HRD` active | 15 | — |
| 37 | `DTEN` active → `WAIT` inactive | 5 | 25 |
| 38 | `WAIT` period | 6T−20 (≈334) | — |
| 39 | `WAIT` inactive → `HRD` active | 0 | — |
| 40 | `HRD` → `WAIT` (setup) | — | 80 |
| 41 | `HRD` active period | 2T (≈118) | — |
| 42 | `HRD` → data valid (setup) | — | **120** |
| 43 | `HRD` inactive → `WAIT` inactive | 2T+10 (≈128) | 4T−75 (≈161) |
| 44 | data valid → data end (hold) | 0 | — |
| 44b| `HRD` active → `DTEN` inactive | 6T−… | — |

Datasheet notes:
1. `WAIT`=LOW appears only if the second `HRD` falling edge does not exceed the indicated
   times.
2. The minimum time for which `WAIT`=LOW does *not* occur.
3. `HRD` LOW and HIGH are assumed ≥ 50 ns.
4. If the `HRD` LOW pulse is 50 < t < 120 ns, the host does **not** read valid data on
   `HD0-7` → the data is guaranteed only after **120 ns** from `HRD`.

→ **Our side (drive)**: the critical constraint is **#42**: present the data on `HD0-7`
**within 120 ns** of `HRD` going active. Also `DTEN`/`EOP` must react to `HRD` within
**120 ns** (#31, #32, #35).

### Rate and bandwidth
- Minimum read period ≈ **6T ≈ 354 ns/byte** ⇒ the chip's peak bandwidth ≈ **2.8 MB/s**
  (consistent with the stated "2.3 MB/s").
- The **CDTV is 1×**: 75 sectors/s × 2048 = **153.6 KB/s ≈ 6.5 µs/byte**, ~18× slower than
  the chip's limit. ⇒ On *rate* we have huge margin; only the **setup/hold** and the
  **≤120 ns response** of the data after `HRD` matter.

---

## 3. Reset timing (Figure 41)

| Parameter | min | max |
|---|----:|----:|
| `RESET` pulse width | 100 | — |
| Controller data hold | — | 50 |
| Controller data delay | — | 50 |
| Host data hold | — | 50 |
| Host data delay | — | 50 |
| RAM data hold/delay | — | 50 |
| `DOUT` hold / delay | — | 100 |
| `STEN`, `DTEN` hold | — | 100 |
| `EOP` hold | — | 100 |
| `INT` hold | — | 100 |

→ `RESET` minimum **100 ns**; all outputs settle/release within 50–100 ns.

---

## 4. Controller side (Figure 42) — internal to our device

These are the bus timings between the drive µC and the LC8951 (`AS`, `CS`, `RD`, `WR`,
`D0-7`): AS setup/hold, CS setup/hold, RD/WR pulse width, access time, data-out delay,
tri-state delay, write data setup/hold. **They are not exposed on CN9**: in the replacement
this logic is implemented internally (firmware + CPLD), so these times are not a constraint
toward the CDTV — we realize them as needed. Not detailed here (unreliable diagram OCR;
consult Figure 42 in the datasheet if a faithful two-bus model needs replicating).

---

## 5. Design implications

1. **Ample throughput margin**: the bottleneck is the CDTV (1×, 6.5 µs/byte), not our
   logic. No exotic hardware is needed for bandwidth.
2. **Tight constraints only on response delays** (≈ tens–120 ns):
   - sample `HD0-7` on the `HWR` edge (command in);
   - present valid data within **120 ns** of `HRD` (data out, #42);
   - update `DTEN`/`STEN`/`EOP` within **105–120 ns** of their respective triggers.
3. **Those 120 ns are perfect for an ATF1508AS CPLD** (typical pin-to-pin delay 7–10 ns):
   the host-interface state machine runs comfortably. Even an RP2350 PIO could hold the
   data-after-HRD, but the 5 V CPLD gives margin and handles the 5 V bus natively.
4. **Suggested partitioning**:
   - *CPLD*: decode `ENABLE`/`CMD`/`HWR`/`HRD`/`SELDRQ`, latch the command byte, drive
     `DTEN`/`STEN`/`DRQ`/`EOP`, mux the data/status byte, meet the #1–#44 timings. It keeps
     a small handoff buffer/register toward the MCU.
   - *RP2350*: prepares the bytes (status, command output, sectors from SD) and makes them
     available to the CPLD before the CDTV requests them (the 6.5 µs/byte margin allows this
     with DMA + double buffering).
5. **`C16M` (= XTALCK, 16.9344 MHz)**: a dedicated crystal oscillator; it is the reference
   `T` of all the times above and is also the audio master clock.

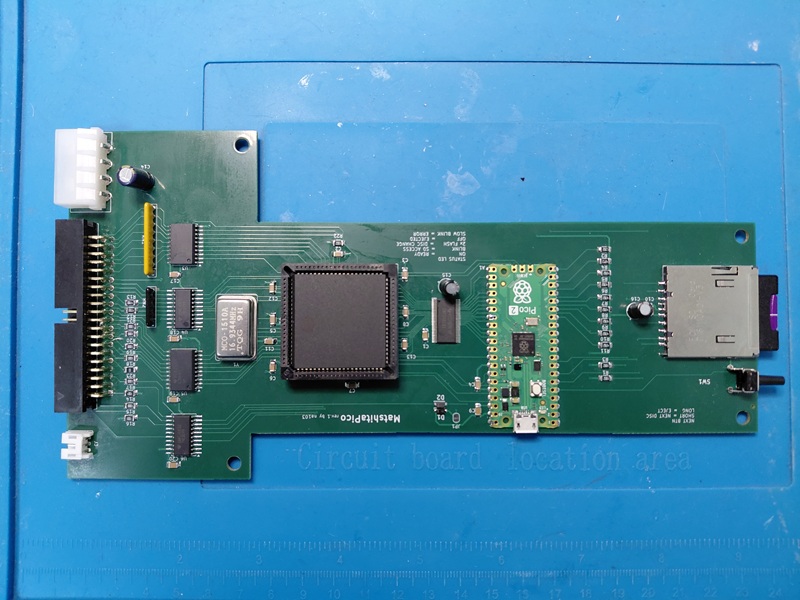
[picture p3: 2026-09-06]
img/mp_beta.jpg

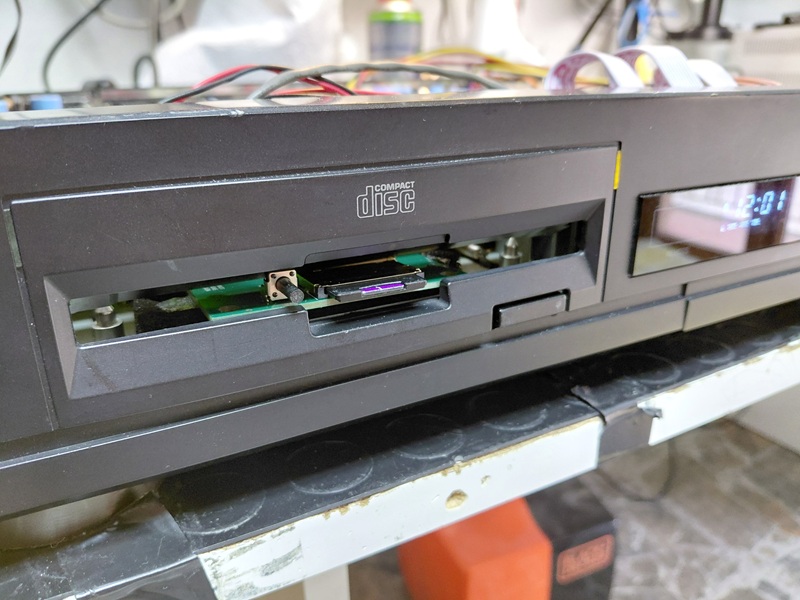
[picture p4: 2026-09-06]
img/mp_cdtv.jpg

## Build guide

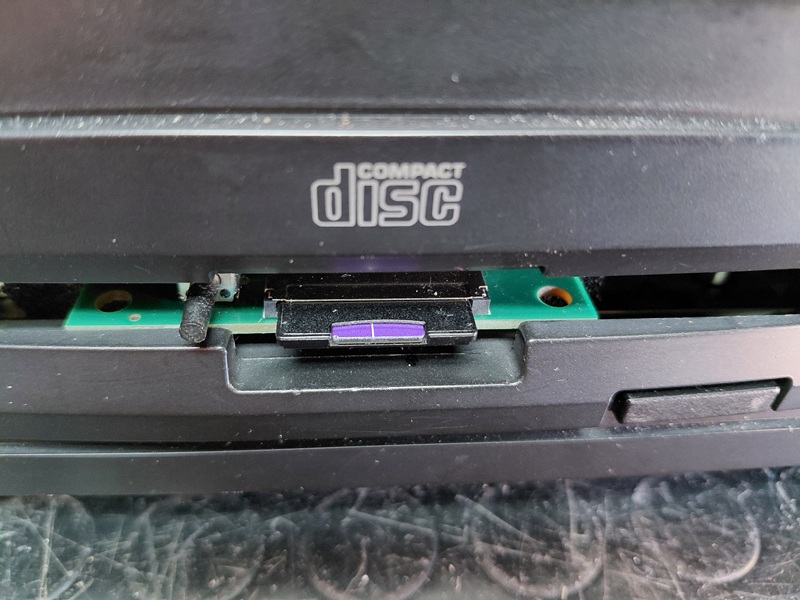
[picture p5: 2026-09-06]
img/beta_assembly/06_beta_assembly.jpg

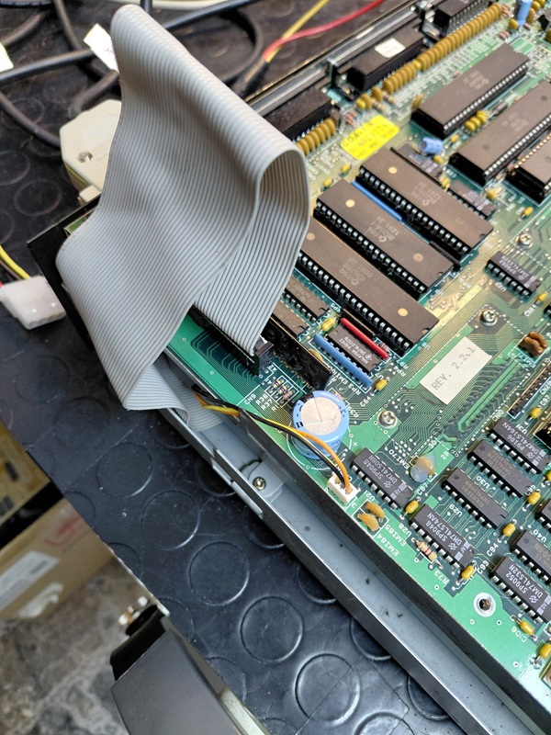
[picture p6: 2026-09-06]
img/beta_assembly/05_beta_assembly.jpg

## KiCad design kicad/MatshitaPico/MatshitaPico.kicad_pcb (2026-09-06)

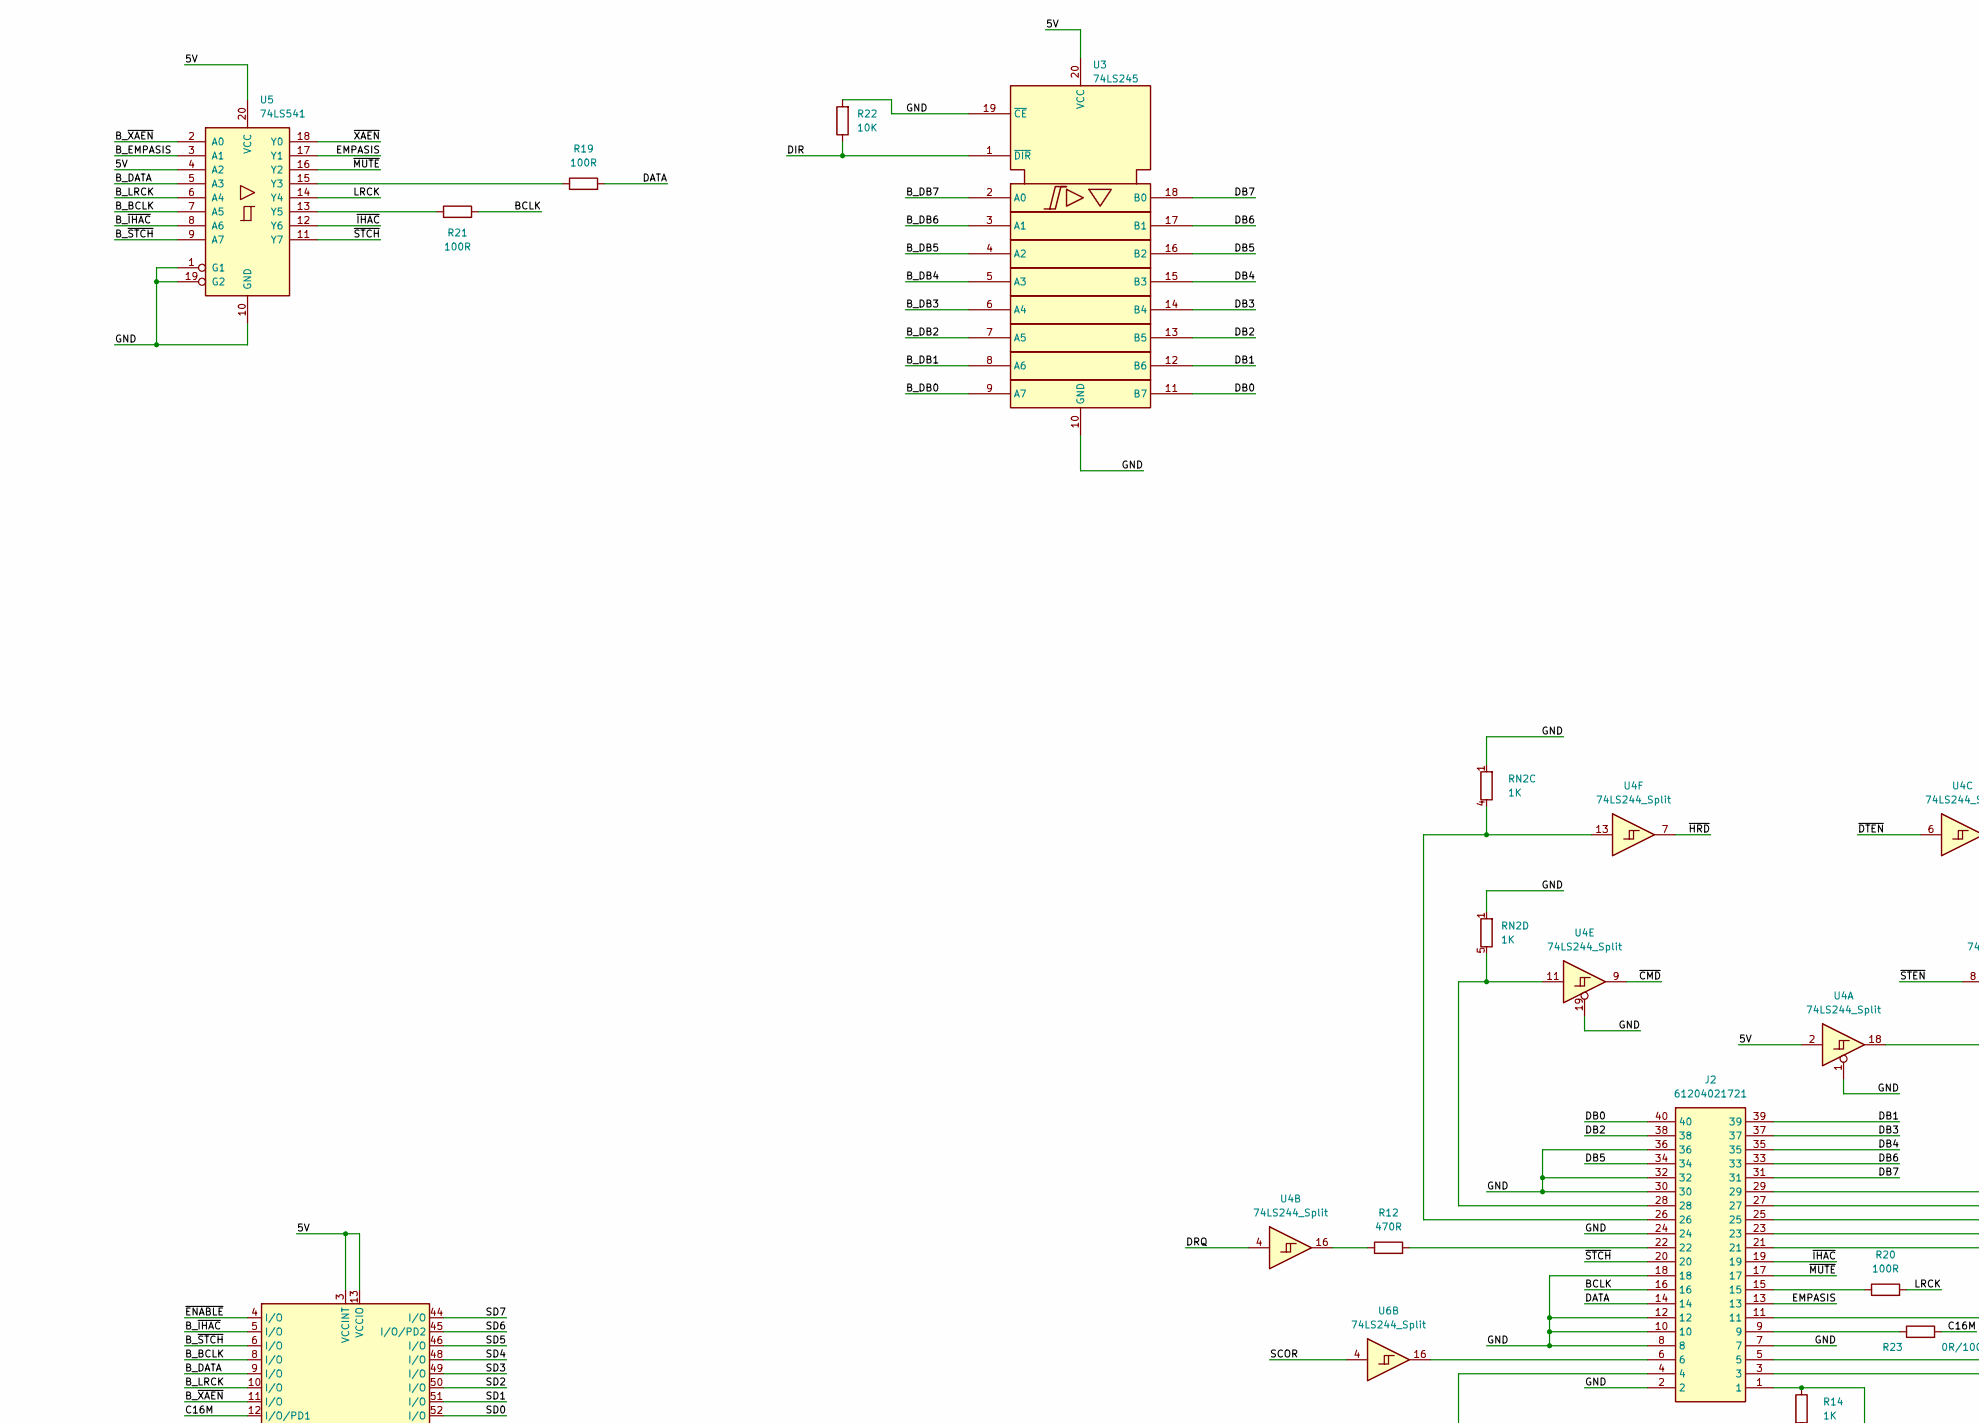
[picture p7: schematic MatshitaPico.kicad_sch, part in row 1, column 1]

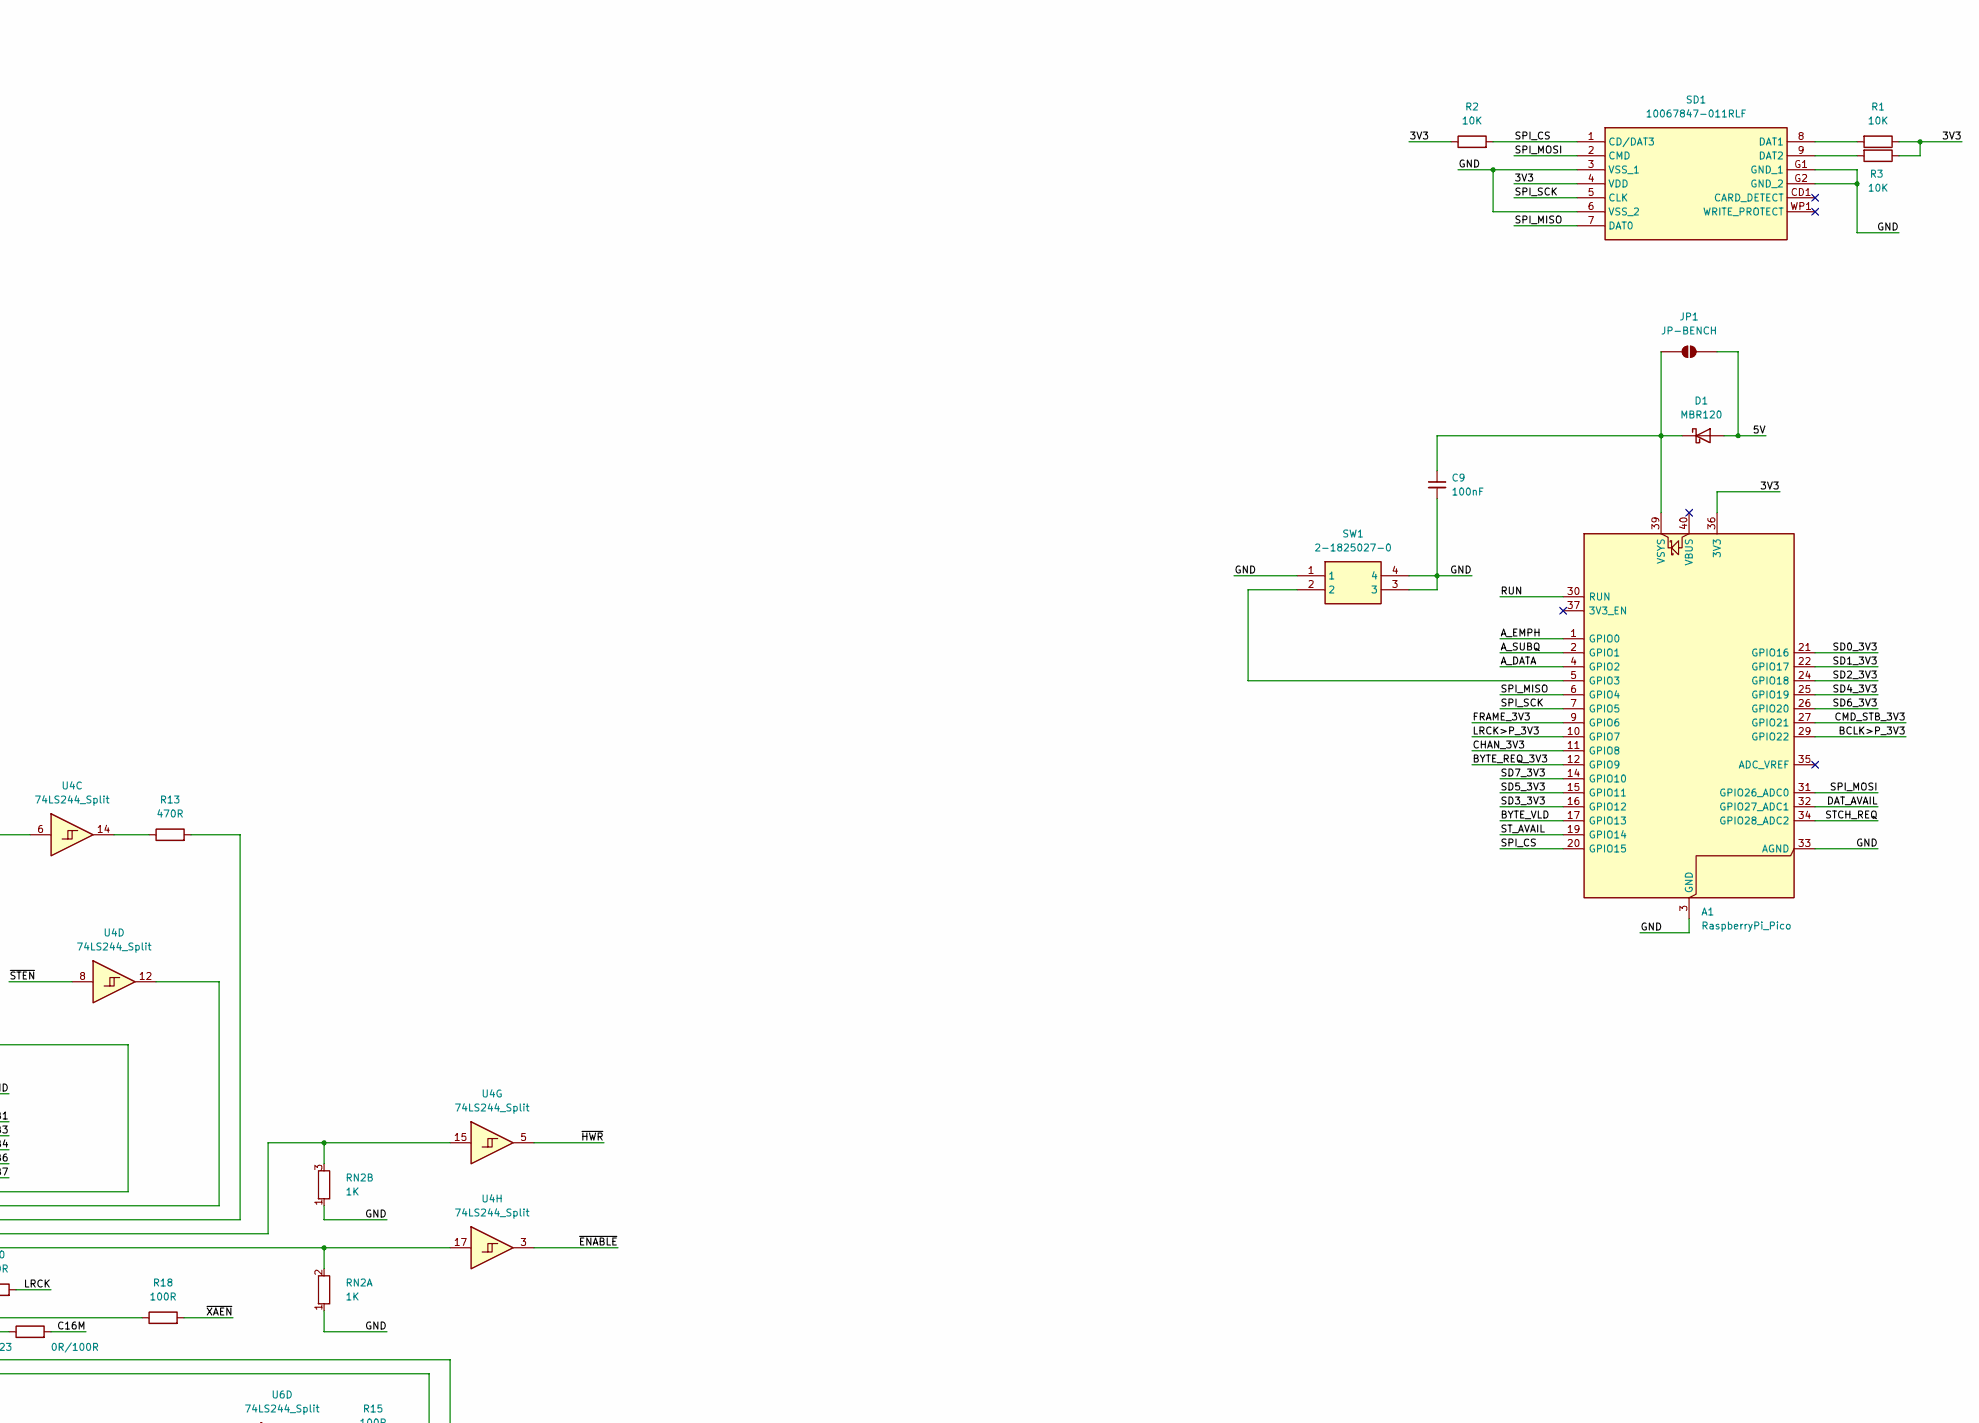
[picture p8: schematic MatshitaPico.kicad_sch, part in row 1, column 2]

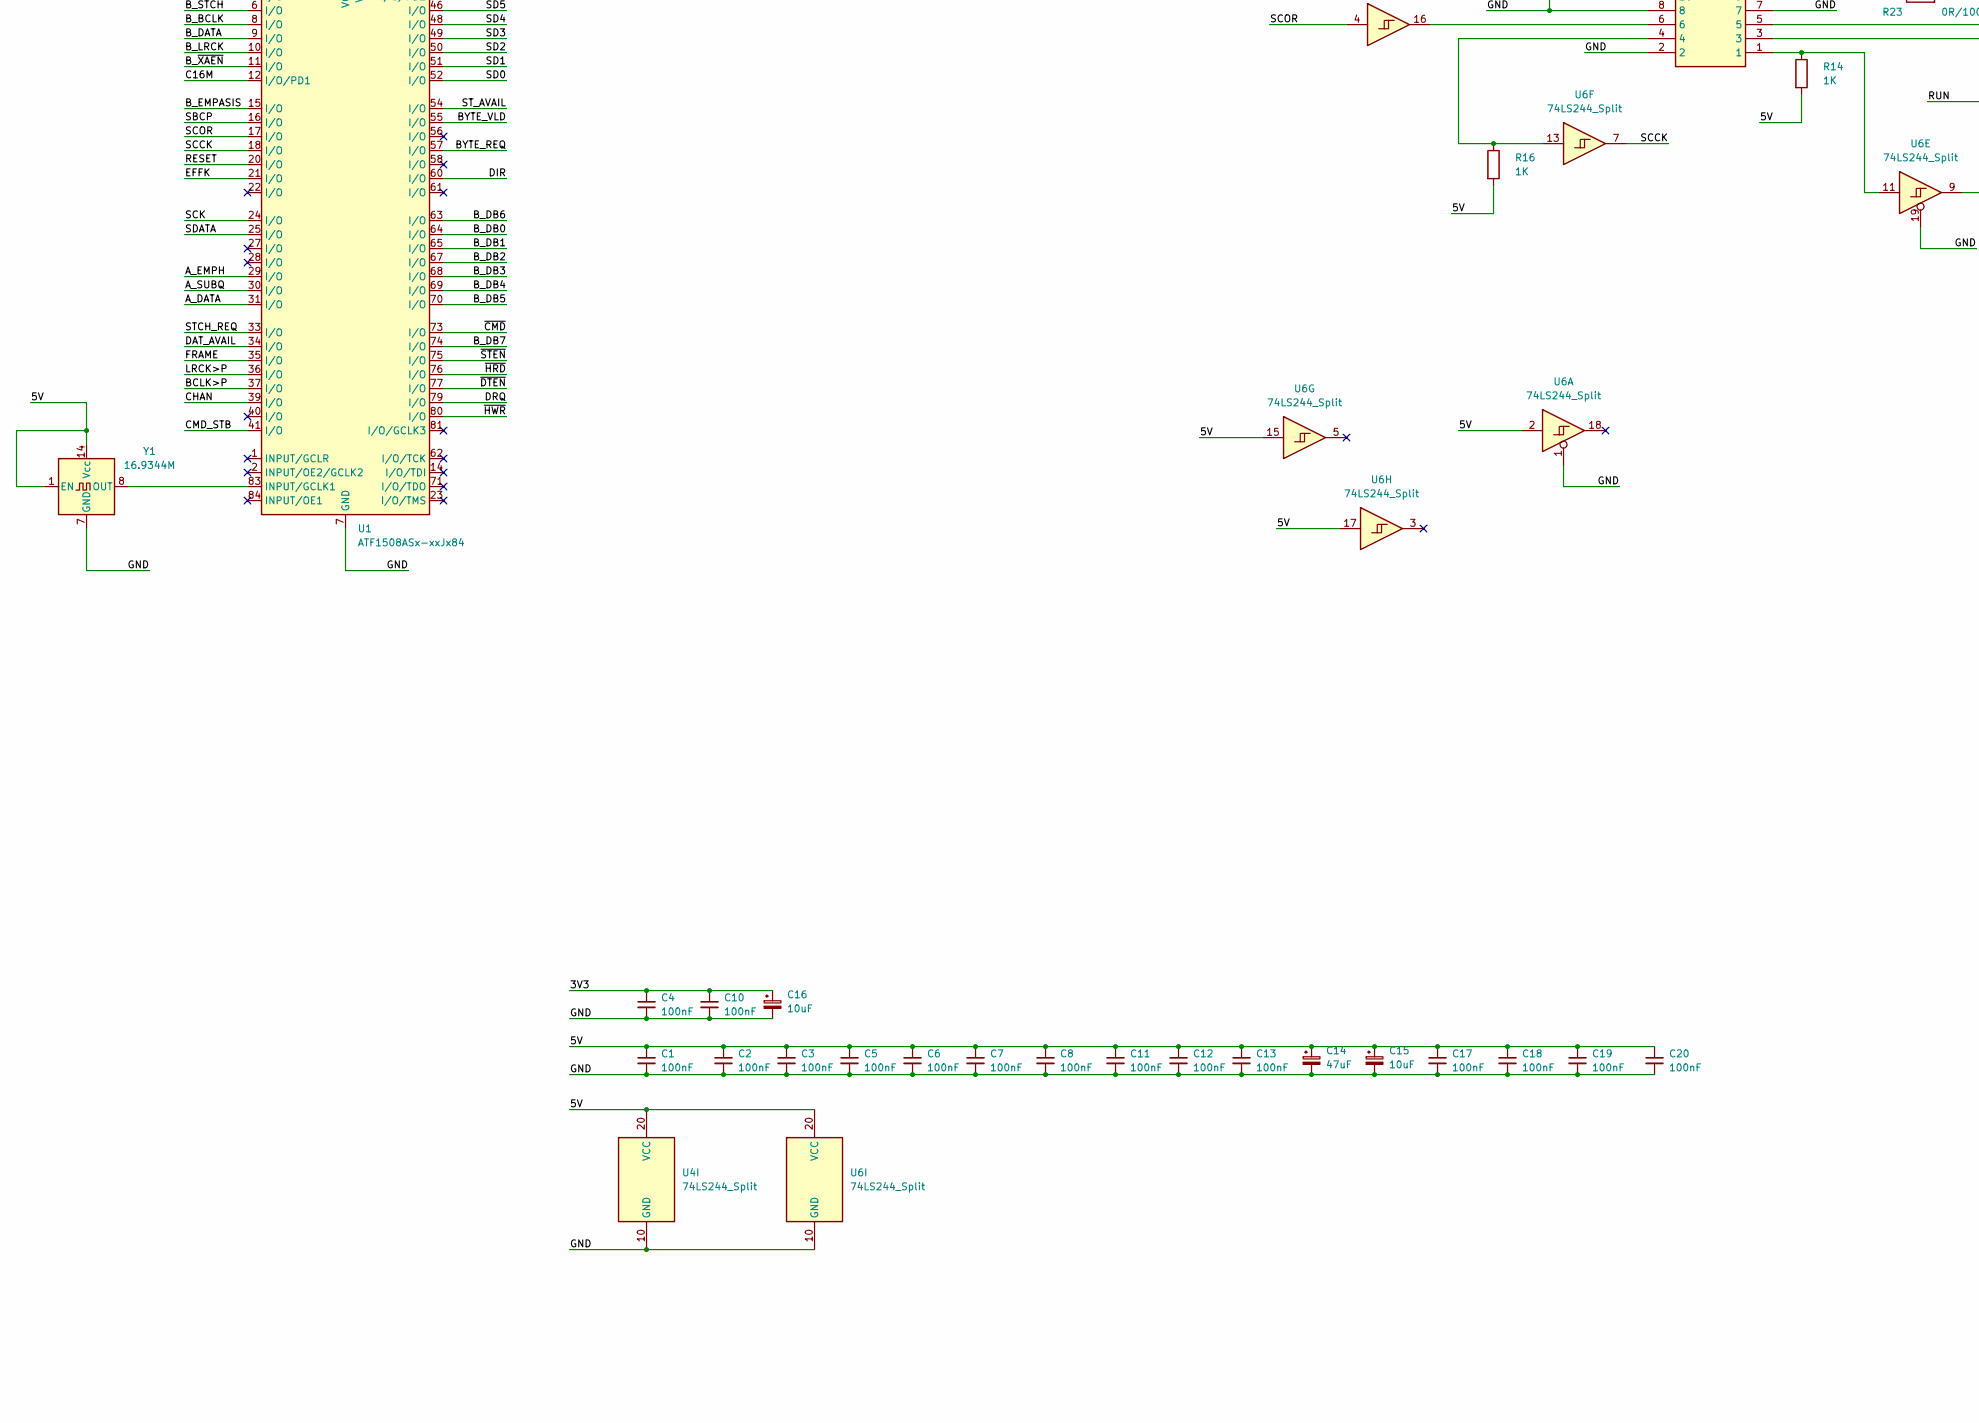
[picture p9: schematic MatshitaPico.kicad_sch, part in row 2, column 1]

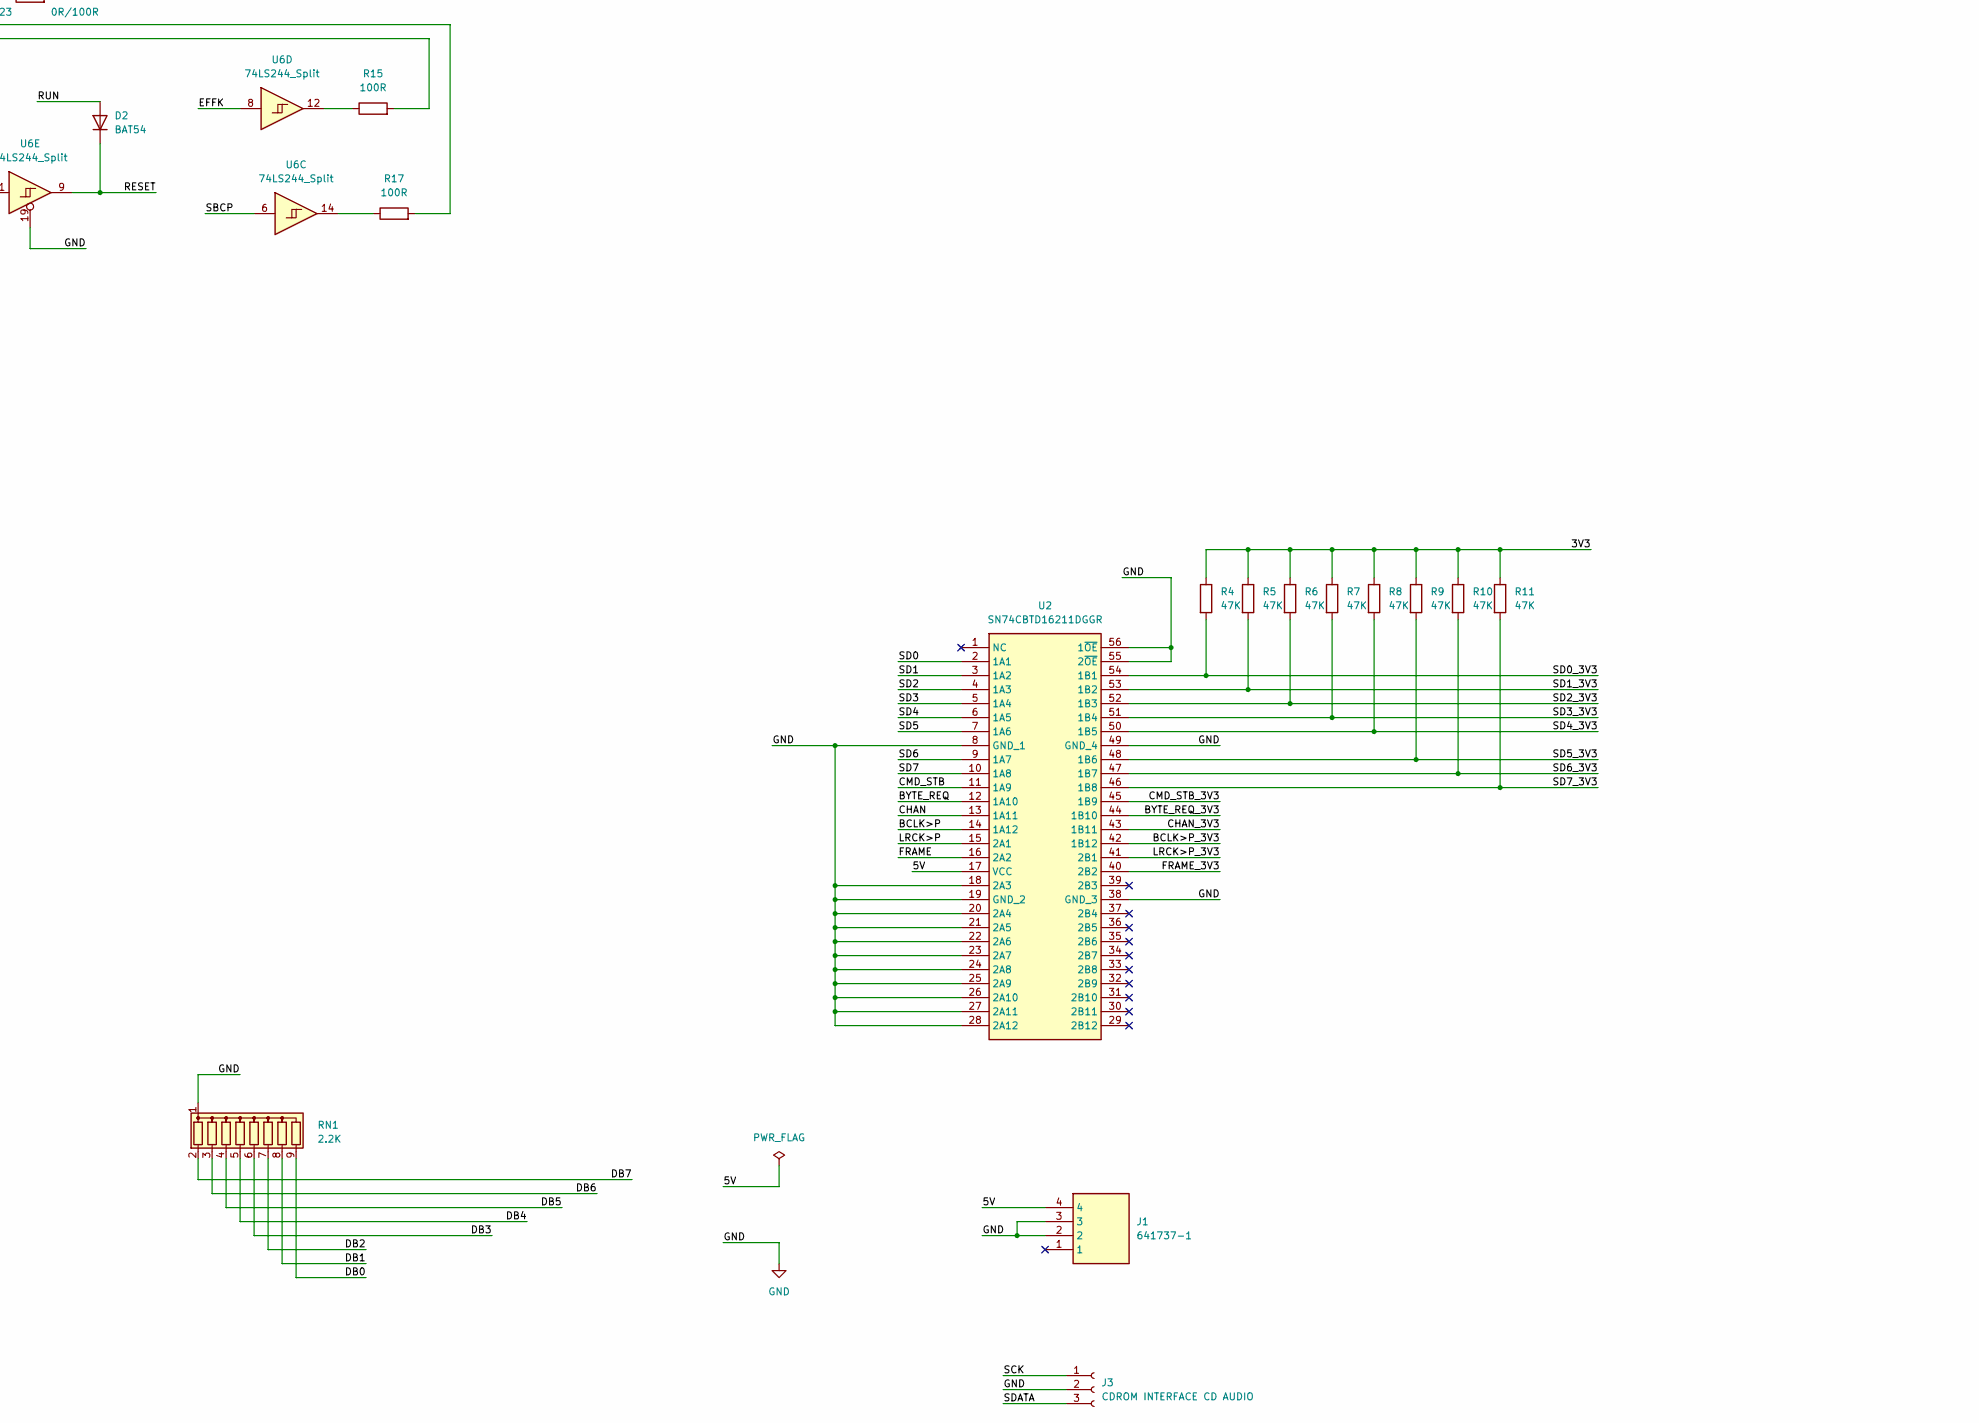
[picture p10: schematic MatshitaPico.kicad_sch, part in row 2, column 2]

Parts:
A1: RaspberryPi_Pico; RaspberryPi_Pico_Common_no_wifi
C1, C2, C3, C4, C5, C6, C7, C8, C9, C10, C11, C12, C13, C17, C18, C19, C20: 100nF; C_1206_3216Metric_Pad1.33x1.80mm_HandSolder
C14: 47uF; CP_Radial_D5.0mm_P2.50mm
C15, C16: 10uF; CP_Radial_D5.0mm_P2.50mm
D1: MBR120; SODFL3616X98N
D2: BAT54; SODFL3616X98N
J1: 641737-1; Mouser Part Number 571-6417371
J2: 61204021721; Mouser Part Number 710-61204021721
J3: CDROM INTERFACE CD AUDIO; JST_PH_S3B-PH-K_1x03_P2.00mm_Horizontal
JP1: JP-BENCH; SolderJumper-2_P1.3mm_Open_RoundedPad1.0x1.5mm
R1, R2, R3, R22: 10K; R_1206_3216Metric_Pad1.30x1.75mm_HandSolder
R4, R5, R6, R7, R8, R9, R10, R11: 47K; R_1206_3216Metric_Pad1.30x1.75mm_HandSolder
R12, R13: 470R; R_1206_3216Metric_Pad1.30x1.75mm_HandSolder
R14, R16: 1K; R_1206_3216Metric_Pad1.30x1.75mm_HandSolder
R15, R17, R18, R19, R20, R21: 100R; R_1206_3216Metric_Pad1.30x1.75mm_HandSolder
R23: 0R/100R; R_1206_3216Metric_Pad1.30x1.75mm_HandSolder
RN1: 2.2K; R_Array_SIP9
RN2: 1K; R_Array_SIP5
SD1: 10067847-011RLF; 10067847011RLF; Mouser Part Number 649-10067847-011RLF
SW1: 2-1825027-0; 218250270; Mouser Part Number 506-2-1825027-0
U1: ATF1508ASx-xxJx84; PLCC-84_THT-Socket
U2: SN74CBTD16211DGGR; SOP50P810X120-56N; Mouser Part Number 595-74CBTD16211DGGR
U3: 74LS245; SOIC-20W_7.5x12.8mm_P1.27mm
U4, U6: 74LS244_Split; SOIC-20W_7.5x12.8mm_P1.27mm
U5: 74LS541; SOIC-20W_7.5x12.8mm_P1.27mm
Y1: 16.9344M; Oscillator_DIP-14

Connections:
/3V3: A1.36 (3V3), C4.1, C10.1, C16.1, R1.1, R2.1, R3.1, R4.1, R5.1, R6.1, R7.1, R8.1, R9.1, R10.1, R11.1, SD1.4 (VDD)
/5V: C1.1, C2.1, C3.1, C5.1, C6.1, C7.1, C8.1, C11.1, C12.1, C13.1, C14.1, C15.1, C17.1, C18.1, C19.1, C20.1, D1.2 (A), J1.4, JP1.2 (B), R14.2, R16.2, U1.3 (VCCINT), U1.13 (VCCIO), U1.26 (VCCIO), U1.38 (VCCIO), U1.43 (VCCINT), U1.53 (VCCIO), U1.66 (VCCIO), U1.78 (VCCIO), U2.17 (VCC), U3.20 (VCC), U4.2, U4.20 (VCC), U5.4 (A2), U5.20 (VCC), U6.2, U6.15, U6.17, U6.20 (VCC), Y1.1 (EN), Y1.14 (Vcc)
/A_DATA: A1.4 (GPIO2), U1.31 (I/O)
/A_EMPH: A1.1 (GPIO0), U1.29 (I/O)
/A_SUBQ: A1.2 (GPIO1), U1.30 (I/O)
/BCLK: J2.16, R21.2
/BCLK>P: U1.37 (I/O), U2.14 (1A12)
/BCLK>P_3V3: A1.29 (GPIO22), U2.42 (1B12)
/BYTE_REQ: U1.57 (I/O), U2.12 (1A10)
/BYTE_REQ_3V3: A1.12 (GPIO9), U2.44 (1B10)
/BYTE_VLD: A1.17 (GPIO13), U1.55 (I/O)
/B_BCLK: U1.8 (I/O), U5.7 (A5)
/B_DATA: U1.9 (I/O), U5.5 (A3)
/B_DB0: U1.64 (I/O), U3.9 (A7)
/B_DB1: U1.65 (I/O), U3.8 (A6)
/B_DB2: U1.67 (I/O), U3.7 (A5)
/B_DB3: U1.68 (I/O), U3.6 (A4)
/B_DB4: U1.69 (I/O), U3.5 (A3)
/B_DB5: U1.70 (I/O), U3.4 (A2)
/B_DB6: U1.63 (I/O), U3.3 (A1)
/B_DB7: U1.74 (I/O), U3.2 (A0)
/B_EMPASIS: U1.15 (I/O), U5.3 (A1)
/B_LRCK: U1.10 (I/O), U5.6 (A4)
/B_~IHAC: U1.5 (I/O), U5.8 (A6)
/B_~STCH: U1.6 (I/O), U5.9 (A7)
/B_~XAEN: U1.11 (I/O), U5.2 (A0)
/C16M: R23.2, U1.12 (I/O/PD1)
/CHAN: U1.39 (I/O), U2.13 (1A11)
/CHAN_3V3: A1.11 (GPIO8), U2.43 (1B11)
/CMD_STB: U1.41 (I/O), U2.11 (1A9)
/CMD_STB_3V3: A1.27 (GPIO21), U2.45 (1B9)
/DATA: J2.14, R19.2
/DAT_AVAIL: A1.32 (GPIO27_ADC1), U1.34 (I/O)
/DB0: J2.40, RN1.9 (R8), U3.11 (B7)
/DB1: J2.39, RN1.8 (R7), U3.12 (B6)
/DB2: J2.38, RN1.7 (R6), U3.13 (B5)
/DB3: J2.37, RN1.6 (R5), U3.14 (B4)
/DB4: J2.35, RN1.5 (R4), U3.15 (B3)
/DB5: J2.34, RN1.4 (R3), U3.16 (B2)
/DB6: J2.33, RN1.3 (R2), U3.17 (B1)
/DB7: J2.31, RN1.2 (R1), U3.18 (B0)
/DIR: R22.1, U1.60 (I/O), U3.1 (~DIR)
/DRQ: U1.79 (I/O), U4.4
/EFFK: U1.21 (I/O), U6.8
/EMPASIS: J2.13, U5.17 (Y1)
/FRAME: U1.35 (I/O), U2.16 (2A2)
/FRAME_3V3: A1.9 (GPIO6), U2.40 (2B2)
/LRCK: R20.2, U5.14 (Y4)
/LRCK>P: U1.36 (I/O), U2.15 (2A1)
/LRCK>P_3V3: A1.10 (GPIO7), U2.41 (2B1)
/RESET: D2.1 (K), U1.20 (I/O), U6.9
/RUN: A1.30 (RUN), D2.2 (A)
/SBCP: U1.16 (I/O), U6.6
/SCCK: U1.18 (I/O), U6.7
/SCK: J3.1, U1.24 (I/O)
/SCOR: U1.17 (I/O), U6.4
/SD0: U1.52 (I/O), U2.2 (1A1)
/SD0_3V3: A1.21 (GPIO16), R4.2, U2.54 (1B1)
/SD1: U1.51 (I/O), U2.3 (1A2)
/SD1_3V3: A1.22 (GPIO17), R5.2, U2.53 (1B2)
/SD2: U1.50 (I/O), U2.4 (1A3)
/SD2_3V3: A1.24 (GPIO18), R6.2, U2.52 (1B3)
/SD3: U1.49 (I/O), U2.5 (1A4)
/SD3_3V3: A1.16 (GPIO12), R7.2, U2.51 (1B4)
/SD4: U1.48 (I/O), U2.6 (1A5)
/SD4_3V3: A1.25 (GPIO19), R8.2, U2.50 (1B5)
/SD5: U1.46 (I/O), U2.7 (1A6)
/SD5_3V3: A1.15 (GPIO11), R9.2, U2.48 (1B6)
/SD6: U1.45 (I/O/PD2), U2.9 (1A7)
/SD6_3V3: A1.26 (GPIO20), R10.2, U2.47 (1B7)
/SD7: U1.44 (I/O), U2.10 (1A8)
/SD7_3V3: A1.14 (GPIO10), R11.2, U2.46 (1B8)
/SDATA: J3.3, U1.25 (I/O)
/SPI_CS: A1.20 (GPIO15), R2.2, SD1.1 (CD/DAT3)
/SPI_MISO: A1.6 (GPIO4), SD1.7 (DAT0)
/SPI_MOSI: A1.31 (GPIO26_ADC0), SD1.2 (CMD)
/SPI_SCK: A1.7 (GPIO5), SD1.5 (CLK)
/STCH_REQ: A1.34 (GPIO28_ADC2), U1.33 (I/O)
/ST_AVAIL: A1.19 (GPIO14), U1.54 (I/O)
/~CMD: U1.73 (I/O), U4.9
/~DTEN: U1.77 (I/O), U4.6
/~ENABLE: U1.4 (I/O), U4.3
/~HRD: U1.76 (I/O), U4.7
/~HWR: U1.80 (I/O), U4.5
/~IHAC: J2.19, U5.12 (Y6)
/~MUTE: J2.17, U5.16 (Y2)
/~STCH: J2.20, U5.11 (Y7)
/~STEN: U1.75 (I/O), U4.8
/~XAEN: R18.2, U5.18 (Y0)
GND: A1.3 (GND), A1.8 (GND), A1.13 (GND), A1.18 (GND), A1.23 (GND), A1.28 (GND), A1.33 (AGND), A1.38 (GND), C1.2, C2.2, C3.2, C4.2, C5.2, C6.2, C7.2, C8.2, C9.2, C10.2, C11.2, C12.2, C13.2, C14.2, C15.2, C16.2, C17.2, C18.2, C19.2, C20.2, J1.2, J1.3, J2.2, J2.7, J2.8, J2.10, J2.12, J2.18, J2.24, J2.30, J2.32, J2.36, J3.2, R22.2, RN1.1 (common), RN2.1 (R1), SD1.3 (VSS_1), SD1.6 (VSS_2), SD1.G1 (GND_1), SD1.G2 (GND_2), SW1.1, SW1.3, SW1.4, U1.7 (GND), U1.19 (GND), U1.32 (GND), U1.42 (GND), U1.47 (GND), U1.59 (GND), U1.72 (GND), U1.82 (GND), U2.8 (GND_1), U2.18 (2A3), U2.19 (GND_2), U2.20 (2A4), U2.21 (2A5), U2.22 (2A6), U2.23 (2A7), U2.24 (2A8), U2.25 (2A9), U2.26 (2A10), U2.27 (2A11), U2.28 (2A12), U2.38 (GND_3), U2.49 (GND_4), U2.55 (2~OE), U2.56 (1~OE), U3.10 (GND), U3.19 (~CE), U4.1, U4.10 (GND), U4.19, U5.1 (G1), U5.10 (GND), U5.19 (G2), U6.1, U6.10 (GND), U6.19, Y1.7 (GND)
unnamed: A1.5 (GPIO3), SW1.2
unnamed: A1.39 (VSYS), C9.1, D1.1 (K), JP1.1 (A)
unnamed: J2.1, R14.1, U6.11
unnamed: J2.3, R15.2
unnamed: J2.4, R16.1, U6.13
unnamed: J2.5, R17.2
unnamed: J2.6, U6.16
unnamed: J2.9, R23.1
unnamed: J2.11, R18.1
unnamed: J2.15, R20.1
unnamed: J2.22, R12.2
unnamed: J2.25, R13.2
unnamed: J2.27, U4.12
unnamed: J2.29, U4.18
unnamed: R12.1, U4.16
unnamed: R13.1, U4.14
unnamed: R15.1, U6.12
unnamed: R17.1, U6.14
unnamed: J2.21, RN2.2 (R1.2), U4.17
unnamed: J2.23, RN2.3 (R2.2), U4.15
unnamed: J2.26, RN2.4 (R3.2), U4.13
unnamed: J2.28, RN2.5 (R4.2), U4.11
unnamed: R1.2, SD1.8 (DAT1)
unnamed: R3.2, SD1.9 (DAT2)
unnamed: U1.83 (INPUT/GCLK1), Y1.8 (OUT)
unnamed: R19.1, U5.15 (Y3)
unnamed: R21.1, U5.13 (Y5)

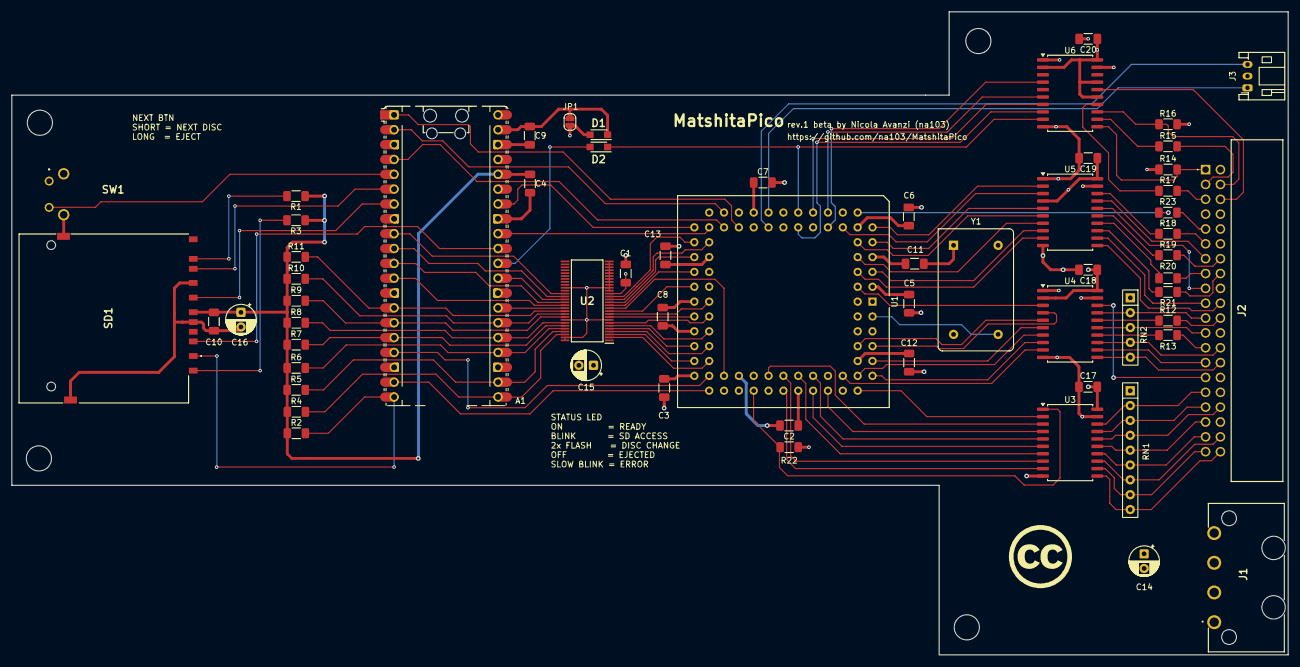
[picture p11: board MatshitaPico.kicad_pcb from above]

Board: 4 copper layers, 218.3 x 110.0 mm, 61 parts (0 on the bottom side), 117 nets.

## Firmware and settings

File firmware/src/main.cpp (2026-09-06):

// =============================================================================
// MatshitaPico -- Solid-state CD-ROM drive replacement for the Commodore CDTV
// Copyright (c) 2026 Nicola Avanzi (na103)
// Licensed under Creative Commons Attribution 4.0 International (CC BY 4.0).
// See LICENSE.
// =============================================================================
// main.cpp -- firmware main loop (RP2350 / Pico 2).
// The CPLD (ATF1508AS) is the real-time front-end on CN9; the Pico implements the
// drive protocol (ported from winuae-ref/cdtv.cpp), reads BIN/CUE images from the
// SD card, generates I2S audio and the subcode Q channel.
// =============================================================================
#include "pico/stdlib.h"

// ---- USB debug: off in the product firmware --------------------------------
// All bring-up logging (logf over USB CDC + boot-log replay on each connection +
// diagnostic heartbeat) is behind USB_DEBUG: at 0 the USB is not even initialised
// (no stdio_init_all -> no CDC device, no background work, no USBCTRL_IRQ
// interference) and logf is a no-op. Overridable from CMake (a separate diagnostic
// build: cmake -DUSB_DEBUG=ON -> a .uf2 with an 8KB ring buffer + replay + heartbeat).
#ifndef USB_DEBUG
#define USB_DEBUG 0
#endif

// Build marker (printed at the top of the boot log): the debug variant self-
// identifies, so a log can never be attributed to the wrong build.
#if USB_DEBUG
 #if defined(SUBCODE_MUTE)
  #define BUILD_TAG "[qplay-dbg-NOSUB]"
 #elif defined(SUBCODE_NOGATE)
  #define BUILD_TAG "[qplay-dbg-NOGATE]"
 #elif defined(SUBCODE_QNEVER)
  #define BUILD_TAG "[qplay-dbg-QNEVER]"
 #elif defined(SUBCODE_QZERO)
  #define BUILD_TAG "[qplay-dbg-QZERO]"
 #elif defined(SUBCODE_ROT)
  #define BT_STR2(x) #x
  #define BT_STR(x) BT_STR2(x)
  #define BUILD_TAG "[qplay-dbg-ROT" BT_STR(SUBCODE_ROT) "]"
 #else
  #define BUILD_TAG "[qplay-dbg]"
 #endif
#else
#define BUILD_TAG "[qplay]"
#endif

#if USB_DEBUG
#include "pico/stdio_usb.h"
#endif
#include "pinmap.h"
#include "host_link.h"
#include "cdtv_drive.h"
#include "cd_image.h"
#include "storage.h"
#ifndef SD_TEST_BREADBOARD
#include "sd_spi_pio.h"
#endif
#include "audio.h"
#include "subcode.h"
#include "ui.h"
#include <cstdio>
#include <cstdarg>
#include <cstring>

// ---- PERSISTENT AUTO-INSERT (final UX) -------------------------------------
// At boot, if the SD state (/matshita.sta) says a disc was INSERTED, re-insert it
// with a simulated spin-up: boot EJECTED (init 81/82/84 + an armed poll at no-media
// = the host shadow primes to 0x20 on its own) + media_insert AUTOINSERT_DELAY_MS
// after the 1st host command -> bit6 transition -> MOUNT in the grey phase = the
// hardware-confirmed mount path. Covers three cases:
//   (a) DISC CHANGE: NEXT saves "inserted N" and inserts -> the CDTV reboots -> in
//       rev.1 _RESET reaches RUN via a BAT54 -> the Pico restarts -> re-insert disc
//       N -> the NEW disc boots.
//   (b) CDTV RESET button: the disc "stays in the caddy" and reboots (real drive).
//   (c) POWER-ON: the machine remembers the last disc used.
// Absent state / -1 (explicit eject) / invalid index = boot EJECTED: the CDTV goes
// to the boot screen and NEXT inserts (disc-change cycle in ui.cpp).
#define AUTOINSERT_DELAY_MS 1500  // simulated spin-up: from the 1st host command to
                                  // the insert. Not a race (150..10000 ms tested
                                  // equivalent): only the bit6 transition matters.

#define CMD_RESYNC_MS 10          // parser resync timeout: a half-received command
                                  // with no new bytes for >10 ms = the 1st byte was
                                  // spurious (ghost) or one was lost -> discard the
                                  // partial. A real command's bytes arrive ~4 us apart
                                  // (with interrupts off); the min inter-command gap is
                                  // >=90 us: 10 ms = 3 orders of margin.

// ---- boot log (USB) with replay --------------------------------------------
// Boot prints happen BEFORE the USB terminal connects and would be lost: they
// accumulate in a buffer and are reprinted on EACH new connection
// (stdio_usb_connected() = terminal DTR). RING BUFFER: keeps the last ~8KB, so a
// NEXT pressed after boot is always visible when draining the buffer.
#if USB_DEBUG
static char   s_bootlog[8192];
static size_t s_bootpos = 0;        // write position (wraps)
static bool   s_bootwrapped = false;

// NOT static: cdtv_drive.cpp uses it (extern) for the [84-dbg] mode-set capture log.
// Writes to the 8KB ring + live, with a timestamp -> coherent timeline.
void logf(const char* fmt, ...) {
    char line[180];
    // TIMESTAMP (ms since boot) at the head of each line: for the mount timeline.
    uint32_t t = to_ms_since_boot(get_absolute_time());
    int pre = snprintf(line, sizeof(line), "[%lu] ", (unsigned long)t);
    if (pre < 0 || pre >= (int)sizeof(line)) pre = 0;
    va_list ap; va_start(ap, fmt);
    vsnprintf(line + pre, sizeof(line) - pre, fmt, ap);
    va_end(ap);
    fputs(line, stdout);
    size_t l = strlen(line);
    for (size_t i = 0; i < l; ++i) {           // circular append (keeps the last 8KB)
        s_bootlog[s_bootpos++] = line[i];
        if (s_bootpos >= sizeof(s_bootlog)) { s_bootpos = 0; s_bootwrapped = true; }
    }
}
#else
// no-op: the arguments are evaluated (no "unused" warnings) but nothing happens;
// the linker drops what was used only inside the prints.
static inline void logf(const char*, ...) {}
#endif

static bool s_boot_ok = false;
static void try_boot();

// AUTO-INSERT (simulated spin-up): armed by try_boot if the persistent state says
// "disc inserted" and the TOC loads; the timer starts at the 1st host command; on
// expiry the main loop does media_insert(). See PERSISTENT AUTO-INSERT.
static bool            s_autoinsert_armed = false;
static int             s_autoinsert_idx   = -1;
static absolute_time_t s_autoinsert_at;

#if USB_DEBUG
static void log_service() {
    static bool was_connected = false;
    bool now = stdio_usb_connected();
    if (now && !was_connected) {
        fputs("\n==== MatshitaPico boot log ====\n", stdout);
        if (s_bootwrapped) {   // ring full: from the oldest (at s_bootpos) to the newest
            fwrite(s_bootlog + s_bootpos, 1, sizeof(s_bootlog) - s_bootpos, stdout);
            fwrite(s_bootlog, 1, s_bootpos, stdout);
        } else {
            fwrite(s_bootlog, 1, s_bootpos, stdout);
        }
        fputs("==== end of boot log ====\n", stdout);
        // Bring-up aid: if boot failed, retry the mount NOW that the terminal is
        // connected -> the SD library init logs are visible live.
        if (!s_boot_ok) {
            fputs("boot failed: retrying the mount...\n", stdout);
            try_boot();
        }
    }
    was_connected = now;
}
#else
static inline void log_service() {}
#endif

// Most common FatFs FRESULTs in clear text (for the log)
static const char* fr_str(int fr) {
    switch (fr) {
        case 0:  return "OK";
        case 1:  return "DISK_ERR (SPI I/O: wiring/contacts?)";
        case 3:  return "NOT_READY (card not responding: CS/power?)";
        case 4:  return "NO_FILE";
        case 5:  return "NO_PATH (missing folder?)";
        case 13: return "NO_FILESYSTEM (reformat FAT32)";
        default: return "see FatFs FRESULT";
    }
}

// Boot/retry: mount SD + scan /games + load(0), with detailed log and LED. Called
// at power-on and (if it failed) on each new terminal connection.
static void try_boot() {
    // This whole function does blocking SD I/O (mount + TOC scan + load + prewarm)
    // while audio runs empty (silence): without service() the ping-pong DMA would
    // underrun and glitch ("tick" at boot). Suspend the I2S stream: SM stopped ->
    // DMA in backpressure -> A_DATA=0 (silence). (pause/resume are no-ops if audio
    // is not yet initialised.)
    audio::pause_stream();
    s_boot_ok = cd_image::boot();

    if (!storage::is_mounted()) {
        logf("SD: mount FAILED, FR=%d %s\n", storage::last_error(),
             fr_str(storage::last_error()));
    } else {
#ifdef SD_TEST_BREADBOARD
        logf("SD: mount OK - SPI1 hardware backend (BREADBOARD variant, carlk3 lib)\n");
#else
        logf("SD: mount OK - PIO-SPI backend on pio2 (PCB pins), card %lu MB\n",
             (unsigned long)(sd_pio::sector_count() / 2048));
#endif
        int n = cd_image::count();
        if (n == 0)
            logf("/games: no .cue found, FR=%d %s\n",
                 storage::last_error(), fr_str(storage::last_error()));
        else {
            logf("/games: %d images\n", n);
            for (int i = 0; i < n; ++i)
                logf("  [%d] %s\n", i, storage::cue_name(i));
        }
        if (n > 0 && !s_boot_ok)
            logf("load(0) FAILED: unreadable cue or parse error\n");
#if ENABLE_MPDISK
        // .hdf hardfiles (mpdisk.device): SCAN the SD root -> populate the list.
        // Without this, hardfile_count() stays 0 -> DETECT reports nunits=0 -> every
        // read = BADADDRESS -> the OFS loops.
        int nh = storage::scan_hardfiles();
        if (nh == 0)
            logf(".hdf in root: none (mpdisk will have 0 units)\n");
        else {
            logf(".hdf in root: %d\n", nh);
            for (int i = 0; i < nh; ++i)
                logf("  hdf[%d] %s (%lu blocks)\n", i, storage::hardfile_name(i),
                     (unsigned long)storage::hardfile_blocks(i));
        }
#endif
    }

    if (s_boot_ok) {
        // Diagnostic check: parse the TOC of ALL images (stresses .bin resolution and
        // file_size() on the real filesystem, e.g. multi-bin Redump). Leaves the index
        // on the last one: the first NEXT inserts [0] by wrap-around.
        for (int i = 0; i < cd_image::count(); ++i) {
            if (cd_image::load(i)) {
                const cd_image::Toc& d = cd_image::toc();
                logf("  [%d] TOC ok: tracks %d-%d, %d files, last_lsn=%lu%s\n",
                     i, d.first_track, d.last_track, d.n_files,
                     (unsigned long)d.last_lsn,
                     d.data_first ? ", track 1 = data" : ", audio only");
                // CD+G diagnostic: was the .sub detected?
                if (d.n_files == 1) {
                    uint64_t want = (d.files[0].size_bytes / cd_image::RAW_SECTOR)
                                    * cd_image::SUB_SECTOR;
                    logf("      sub %s: %s (expected %lu B, found %lu B)\n",
                         cd_image::sub_name(),
                         cd_image::has_sub() ? "OK" : "NO",
                         (unsigned long)want,
                         (unsigned long)storage::file_size(cd_image::sub_name()));
                }
            } else {
                logf("  [%d] TOC FAILED: unreadable cue or parse error\n", i);
            }
        }
        // Persistent state: if a disc was inserted (NEXT saves it BEFORE the insert,
        // a long eject saves -1), re-insert it with the simulated spin-up = the
        // confirmed mount path. See PERSISTENT AUTO-INSERT.
        int last = storage::load_last_disc();
        if (last >= 0 && last < cd_image::count() && cd_image::load(last)) {
            cd_image::prewarm();         // warm the file (LINKMAP+XIP) before play
            s_autoinsert_idx   = last;
            s_autoinsert_armed = true;   // the timer starts at the 1st host command
            ui::set_led(ui::Led::Ejected);
            logf("SD state: disc [%d] inserted -> auto-insert in %ums after the 1st host command: %s\n",
                 last, (unsigned)AUTOINSERT_DELAY_MS, storage::cue_name(last));
        } else {
            // Boot EJECTED: no media inserted, like a real drive with no caddy. The
            // CDTV stays on the wait screen until NEXT inserts a disc (cd_media = 0).
            ui::set_led(ui::Led::Ejected);
            logf("boot EJECTED (SD state: %d): NEXT inserts disc [0]\n", last);
        }
    } else {
        ui::set_led(ui::Led::Error);    // no image / SD error
        logf("LED: Error (1 Hz blink)\n");
    }

    audio::resume_stream();             // SD I/O done: resume the I2S stream
}

int main() {
#if USB_DEBUG
    stdio_init_all();          // log over USB (debug, off the connector GPIOs)
#endif

    // Initialisation
    host_link::init();         // data bus + handshake with the CPLD
    audio::init();             // I2S slave (A_DATA), clocks from the CPLD
    subcode::init();           // Q channel (A_SUBQ)
    ui::init();                // NEXT button (GP3) + LED (GP25)
    cdtv::init();              // drive state

    // Build marker at the top of the boot log: each test self-identifies.
    logf("firmware build: %s %s %s\n", __DATE__, __TIME__, BUILD_TAG);

    // Boot: mount SD, pick the image, build the TOC, signal media present. RETRY on
    // cold boot: from cold the card may not be ready yet (mount FR=3 NOT_READY on the
    // first power-on, OK on later reboots via RESET->RUN). Without retry, a cold
    // USB-off boot stays disc-less. The 1st host command arrives at ~2.4 s: 5 tries
    // x 300 ms fit comfortably.
    try_boot();
    for (int r = 0; r < 5 && !s_boot_ok; ++r) {
        sleep_ms(300);
        logf("SD not ready: retry mount %d/5...\n", r + 1);
        try_boot();
    }

    // ---- drive announce to the host (STCH at boot) ---------------------------
    // The real drive asserts STCH at reset (cdtv.cpp cdtv_reset_int: stch=1) to make
    // itself detected: that initial STCH makes the CDTV start the CD task (TPI INT2);
    // only then does the host poll status and write commands. We boot EJECTED and did
    // not announce -> the CDTV never started the dialogue. We announce here and RE-
    // announce periodically until the host writes the first command, so we do not
    // depend on the CDTV's reset<->TPI-setup timing. After the first command, STCH is
    // event-driven again.
    bool host_seen = false;
    bool s_suppress_rd = false;   // suppresses the "rd st" of a duplicate 0x81 poll (log dedup)
    absolute_time_t next_announce = get_absolute_time();

    // ---- model of the CPLD's output FIFO (word engine) -----------------------
    // The CPLD has a 2-slot alternating FIFO (host_if.v): the CDTV DMAC is a WORD
    // engine (2 back-to-back _HRD reads ~212 ns per DRQ cycle) and DRQ rises only on
    // a complete word (fill==2). Each command byte FLUSHES the CPLD FIFO (realignment
    // + DRQ suspension during commands): the firmware keeps the model of the contents
    // here and re-pushes the flushed data bytes at the end of a reply ("interlude").
    // BYTE_REQ is a toggle: ONE event per byte consumed (even in a pair).
    uint8_t s_fifo_val[2] = {0, 0};    // FIFO contents in order (0 = next read)
    uint8_t s_fifo_n      = 0;         // bytes we believe are still in the FIFO
    bool    s_fifo_is_data = false;    // true = holds DATA bytes (replay candidates)
    uint8_t s_replay[2]   = {0, 0};    // data bytes flushed by a command, to re-push
    uint8_t s_replay_n    = 0;
    bool    s_status_interlude = false; // status reply in progress WHILE a data transfer is active

    // FIFO DESYNC DIAGNOSTIC: invariant D = push - cons - replay. push = DATA bytes
    // pushed to the CPLD; cons = data-channel BYTE_REQ events (host consumes); replay
    // = re-pushed bytes. With the channel quiet D MUST be 0: D>0 = pushes swallowed,
    // never reaching the host (LOST bytes); D<0 = the host consumed bytes never
    // pushed (STALE reads = the ~300 ns flush race inside an _HRD pair).
    uint32_t s_dbg_push = 0, s_dbg_cons = 0, s_dbg_replay = 0;

#if USB_DEBUG
    // "scratch" glitch measurement window at the 1st play: armed by a play command,
    // counts host traffic and at the end dumps the audio metrics (accumulated in RAM
    // by audio.cpp -> no live logf during the critical window, so the USB Heisenbug
    // does not inflate the very measurements we want).
    absolute_time_t s_audbg_at{};
    bool            s_audbg_armed = false;
    uint32_t        s_audbg_cmds  = 0;   // host command bytes seen in the window
#endif

    // push a byte to the CPLD, updating the model
    auto push_out = [&](uint8_t v, bool is_data) {
        host_link::send_byte(v);
        if (s_fifo_n < 2) s_fifo_val[s_fifo_n++] = v;
        s_fifo_is_data = is_data;
        if (is_data) s_dbg_push++;
    };
    // (re)start/resume the data channel: replay the flushed bytes + top-up to 2 + DRQ
    auto resume_data = [&]() {
        s_dbg_replay += s_replay_n;
        for (uint8_t i = 0; i < s_replay_n; ++i) push_out(s_replay[i], true);
        s_replay_n = 0;
        while (s_fifo_n < 2 && cdtv::data_pending())
            push_out(cdtv::next_data_byte(), true);
        host_link::set_data_avail(s_fifo_n != 0);
    };

    // ---- main loop -----------------------------------------------------------
    // CMD_STB/BYTE_REQ edges are captured on IRQ (host_link) and queued; here we
    // consume the rings. The CPLD asserts STEN/DRQ only with a fresh byte loaded
    // (out_valid) -> the FIRST byte of a reply is pushed as soon as the command
    // completes; the rest on BYTE_REQ.
    while (true) {
        // 0) periodic STCH announce until the disc is mounted (TOC read). The 6525
        //    latches STCH in the AIR ONLY in INTERRUPT mode; in I/O mode it discards
        //    it. At boot we are in I/O mode, so we keep pulsing STCH slowly until the
        //    host enters interrupt mode and the ROM arms its shadow to bit6=0, then
        //    the insert (media) drives the mount. Announce only while media is ABSENT
        //    (the real drive emits ONE STCH per media change); resumes after an eject.
        if (!cdtv::state().media && !cdtv::toc_read() && time_reached(next_announce)) {
            host_link::pulse_stch();
            next_announce = make_timeout_time_ms(150);
        }

        // 1) command byte arriving from the CPLD?
        static uint32_t s_last_cmd_byte_ms = 0;     // for the resync (see 1-bis)
        uint8_t cb;
        if (host_link::poll_cmd_byte(&cb)) {
#if USB_DEBUG
            if (s_audbg_armed) s_audbg_cmds++;   // host traffic in the measurement window
#endif
            s_last_cmd_byte_ms = to_ms_since_boot(get_absolute_time());
            bool first = !host_seen;
            host_seen = true;                       // the host talks -> stop the boot announce
            if (first && s_autoinsert_armed)        // simulated spin-up: timer from the 1st command
                s_autoinsert_at = make_timeout_time_ms(AUTOINSERT_DELAY_MS);
            host_link::release_stch();              // the host is servicing the event -> release
                                                    // the STCH level (real drive/WinUAE: stch=0
                                                    // on the command)

            // BEFORE snapshotting the FIFO for replay: apply the consumes ALREADY
            // queued (BYTE_REQ events that arrived before this command byte = before
            // the CPLD flush). Without this drain, with DMA active the model is stale
            // and replay saves bytes ALREADY consumed by the host -> duplicates in the
            // stream on resume = corrupt buffer. No top-up here: the hw FIFO is about
            // to be / already is flushed.
            {
                bool req_id;
                while (host_link::poll_byte_req(&req_id)) {
                    if (req_id) s_dbg_cons++;
                    if (s_fifo_n) { s_fifo_n--; s_fifo_val[0] = s_fifo_val[1]; }
                }
            }

            // EACH command byte FLUSHES the CPLD FIFO (host_if.v, realignment): align
            // the model. In-flight DATA bytes are saved for replay at the end of the
            // reply; flushed status contents = discarded (stale output). DRQ is
            // already down in the CPLD (fill=0) = transfer suspended.
            if (s_fifo_n && s_fifo_is_data && s_replay_n == 0) {
                s_replay_n  = s_fifo_n;
                s_replay[0] = s_fifo_val[0];
                s_replay[1] = s_fifo_val[1];
            }
            s_fifo_n = 0;

            // REPLY FIRST, LOG LATER. USB CDC is very slow (~60 us/line): logging
            // before set_status_avail delayed _STEN by ~180 us -> the CDTV timed out
            // on the status read. The real drive updates STEN within ~105 ns; we must
            // stay within a few us.
            bool complete = cdtv::feed_command_byte(cb);

#if ENABLE_MPDISK
            // BULK-RX (hardfile write): if the byte just processed was the WRITE
            // command (0x61), bulk-rx is now ARMED. The cnt*512 payload bytes arrive
            // ~1 us/byte (the host pushes them back-to-back); a heavy main loop would
            // take them at ~5-20 us/byte -> the CPLD's 2-byte FIFO overflows -> lost
            // bytes -> corrupt block on SD. Drain the payload HERE, at max speed
            // (poll+feed only), until written. Guard timeout: if the host stops mid-
            // way we do not hang.
            if (cdtv::bulk_rx_active()) {
                uint32_t idle = 0;
                while (cdtv::bulk_rx_active()) {
                    uint8_t wb;
                    if (host_link::poll_cmd_byte(&wb)) { cdtv::feed_command_byte(wb); idle = 0; }
                    else if (++idle > 2000000u) { cdtv::bulk_rx_abort(); break; }
                }
                continue;   // payload handled: 0x61 has no status/data, restart the loop
            }
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

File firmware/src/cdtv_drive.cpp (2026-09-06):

// =============================================================================
// MatshitaPico -- Solid-state CD-ROM drive replacement for the Commodore CDTV
// Copyright (c) 2026 Nicola Avanzi (na103)
// Licensed under Creative Commons Attribution 4.0 International (CC BY 4.0).
// See LICENSE.
// =============================================================================
// cdtv_drive.cpp -- see cdtv_drive.h.
// Ported from winuae-ref/cdtv.cpp (cdrom_command_thread lines ~524-696 + helpers
// cdrom_subq/cdrom_info/read_toc/cdrom_modeset/play_cd/play_cdtrack/read_sectors)
// and docs/protocol-cdtv.md. The TOC comes from the CUE parser (cd_image); storage
// and audio are implemented (see storage.cpp / audio.cpp).
// =============================================================================
#include "cdtv_drive.h"
#include "cd_image.h"
#include "cdrom_util.h"
#include "audio.h"
#include "storage.h"
#include <cstring>

// Bring-up diagnostic: report "disc ready" status (media+motor+ready=0x60) instead
// of 0x41, to test whether the ROM waits for drive-ready before reading the TOC.
// Set to 0 for the reference behaviour (0x41).
#define BRINGUP_STATUS_READY 0

#if USB_DEBUG
extern void logf(const char* fmt, ...);   // defined in main.cpp (8KB ring + live)
#endif

namespace cdtv {

static DriveState s;

// ---- command / output buffers ------------------------------------------------
static uint8_t  cmd_buf[8];
static uint8_t  cmd_len = 0, cmd_need = 0;
static uint8_t  out_buf[16];
static uint8_t  out_len = 0, out_idx = 0;

#if ENABLE_MPDISK
// ---- bulk-rx (hardfile WRITE 0x61): the HWR bytes after a WRITE command are data,
// not commands -> feed_command_byte diverts them here while bulk_rx_left>0.
static uint8_t  hdf_wbuf[storage::HDF_BLOCK];  // block being accumulated
static uint32_t bulk_rx_left = 0;              // data bytes still expected via HWR
static uint32_t hdf_wlba = 0;                  // current write LBA
static uint8_t  hdf_wunit = 0;
static uint16_t hdf_wpos = 0;                  // position in the current block
static bool     hdf_werr = false;              // write error during bulk-rx
#endif

// ---- data transfer (CD read 0x02 / hardfile read 0x62) -----------------------
static uint32_t data_sectors_left = 0;   // sectors/blocks still to deliver
static uint8_t  raw_sec[cd_image::RAW_SECTOR];
static uint16_t raw_pos = 0;             // position in the current sector payload
static uint16_t raw_payload_off = 0;     // payload offset within the raw 2352
static uint16_t xfer_size = 2352;        // bytes per unit (CD=sector_size, HDF=512)
static bool     raw_valid = false;       // raw_sec holds a valid sector

// DMA data channel source: CD (cd_image) or hardfile (.hdf via storage). The mpdisk
// pipe (0x60-0x64) and the CD are EXCLUSIVE in v1 -> they share the same transfer
// machine (data_sectors_left/raw_*), one transfer at a time. With ENABLE_MPDISK OFF
// only SRC_CD remains and the hardfile branches disappear.
enum DataSource { SRC_CD, SRC_HDF };
static DataSource data_src = SRC_CD;
#if ENABLE_MPDISK
static uint8_t    hdf_unit = 0;          // hardfile unit being read
static uint32_t   hdf_lba  = 0;          // current read LBA (0x62)
#endif
static bool     xfer_started = false;    // the just-executed command STARTED a read
                                         // (one-shot for main: take_xfer_started).
                                         // Distinguishes "this command starts the
                                         // transfer" (push 1st byte) from "command
                                         // completed WHILE a transfer is in progress"
                                         // (poll 0x81: do NOT push data).

// ---- STCH (async notification) -----------------------------------------------
static bool stch_pending = false;
static void request_stch() { stch_pending = true; }

// ---- "mounted": the host has read the TOC (0x8a) = mount done ----------------
// Used by the announce loop (main.cpp) to STOP pulsing STCH once mounted. While
// false, boot pulses STCH slowly -> the host enters interrupt mode (the 6525
// latches STCH only in interrupt mode) and the ROM arms its shadow to bit6=0.
static bool s_toc_read = false;
bool toc_read() { return s_toc_read; }

DriveState& state() { return s; }

// Expected command length per opcode (protocol §3).
static uint8_t cmd_length(uint8_t op) {
    switch (op) {
        // 0x00 = 1-byte NOP/filler: the ROM's armed poll sends it as the trailing
        // byte of "81 00" (size=1, count=1 -> sends 2 bytes: 81 00). 0x81 is 1 byte,
        // so the trailing 00 is filler. Treating it as a 2-byte command would eat
        // the next opcode 0x82 -> the parser would misalign and 0x82/0x84 would
        // NEVER execute. 1 byte, no reply (see execute()).
        case 0x00: return 1;
        case 0x80: return 2;
        case 0x81: case 0x85: case 0x86: case 0x88: case 0xa2: return 1;
        default: return 7;  // 0x01/02/04/05/09/0a/0b/82/83/84/87/89/8a/8b/a3 + unknown
    }
}

static void put_out(const uint8_t* p, int n) {
    if (n < 0) n = 0;
    if (n > (int)sizeof(out_buf)) n = sizeof(out_buf);
    memcpy(out_buf, p, n); out_len = (uint8_t)n; out_idx = 0;
}

static uint8_t status_byte() {
    uint8_t v = 0;
    // bit0 (0x01): in the reference it is !cd_isready, but cd_isready is ALWAYS 0
    // (the countdown is #if 0 and never set positive, cdtv.cpp) -> the real drive
    // reports bit0 ALWAYS set: ejected=0x01, with media=0x41. The CDTV expects this
    // pattern; with 0x40 (bit0 missing) it did not proceed to read the TOC. s.ready
    // stays informational only.
#if BRINGUP_STATUS_READY
    // Bring-up diagnostic: with media report 0x60 = media + motor + READY (bit0=0);
    // ejected stays 0x01. Temporary.
    if (s.media) { v |= 0x40 | 0x20; }   // media + motor, bit0 (not-ready) NOT set
    else         { v |= 0x01; }          // ejected: not-ready
    if (s.playing)   v |= 0x04;
    if (s.finished)  v |= 0x08;
    if (s.error)     v |= 0x10;
    return v;
#else
    v |= 0x01;
    if (s.playing)   v |= 0x04;
    if (s.finished)  v |= 0x08;
    if (s.error)     v |= 0x10;
    if (s.motor)     v |= 0x20;
    if (s.media)     v |= 0x40;
    return v;
#endif
}
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

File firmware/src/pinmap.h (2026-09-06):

// =============================================================================
// MatshitaPico -- Solid-state CD-ROM drive replacement for the Commodore CDTV
// Copyright (c) 2026 Nicola Avanzi (na103)
// Licensed under Creative Commons Attribution 4.0 International (CC BY 4.0).
// See LICENSE.
// =============================================================================
// pinmap.h -- RP2350 / Pico 2 (A1) GPIO assignment.
// This is extracted from the KiCad schematic and is the hardware truth: the PCB
// is already routed on these pins. Do NOT change them without re-routing the PCB.
// Budget: 26/26 GPIO used (GP0-GP22 + GP26/27/28); GP23/24/25 are module-internal,
// GP25 = onboard status LED.
//
// CPLD contract (host_if.v / MatshitaPico_top.v):
//   CPLD -> Pico (via SN74CBTD16211, 5V->3.3V): CMD_STB, BYTE_REQ, CHAN, BCLK, LRCK, FRAME
//   Pico -> CPLD (direct, 3.3V->TTL):           BYTE_VLD, ST_AVAIL, DAT_AVAIL, STCH_REQ,
//                                               A_DATA, A_SUBQ, A_EMPH
//   bidirectional data bus (via shifter):       SD0..SD7
// =============================================================================
#pragma once
#include "pico/stdlib.h"

// ---- Host data bus SD[7:0] (bidirectional, via SN74CBTD16211) ----------------
// NOT contiguous: no PIO on the bus, use gather/scatter (see host_link.cpp). At
// CDTV rates (~6.5 us/byte at 1x) software gather/scatter is more than enough.
static constexpr uint PIN_SD0 = 16;
static constexpr uint PIN_SD1 = 17;
static constexpr uint PIN_SD2 = 18;
static constexpr uint PIN_SD3 = 12;
static constexpr uint PIN_SD4 = 19;
static constexpr uint PIN_SD5 = 11;
static constexpr uint PIN_SD6 = 20;
static constexpr uint PIN_SD7 = 10;
static constexpr uint PIN_SD[8] = {
    PIN_SD0, PIN_SD1, PIN_SD2, PIN_SD3, PIN_SD4, PIN_SD5, PIN_SD6, PIN_SD7
};
// mask of all data-bus bits (for gpio_set_dir_masked / get_all)
static constexpr uint32_t SD_BUS_MASK =
    (1u<<PIN_SD0)|(1u<<PIN_SD1)|(1u<<PIN_SD2)|(1u<<PIN_SD3)|
    (1u<<PIN_SD4)|(1u<<PIN_SD5)|(1u<<PIN_SD6)|(1u<<PIN_SD7);

// ---- Handshake CPLD -> Pico (inputs) -----------------------------------------
static constexpr uint PIN_CMD_STB  = 21;  // pulse: command byte on SD[] from the CPLD
static constexpr uint PIN_BYTE_REQ = 9;   // pulse: "give me the next byte" (status/data)
static constexpr uint PIN_CHAN     = 8;   // 0 = status, 1 = data (which next byte)

// ---- Handshake Pico -> CPLD (outputs) ----------------------------------------
static constexpr uint PIN_BYTE_VLD  = 13;  // valid byte placed on SD[] by the Pico
static constexpr uint PIN_ST_AVAIL  = 14;  // status bytes available -> STEN
static constexpr uint PIN_DAT_AVAIL = 27;  // data transfer ready -> DRQ
static constexpr uint PIN_STCH_REQ  = 28;  // async notification request -> STCH

// ---- Audio clocks from the CPLD (inputs; I2S slave) --------------------------
static constexpr uint PIN_BCLK  = 22;  // bit clock (C16M/8 = 48 fs)
static constexpr uint PIN_LRCK  = 7;   // L/R clock (fs = 44.1 kHz, high = L)
static constexpr uint PIN_FRAME = 6;   // KiCad net "FRAME", reused as SCOR: subcode
                                       // block sync (75 Hz) for the subq_tx PIO
                                       // (I2S aligns on LRCK, no longer needs it)

// ---- Audio / subcode Pico -> CPLD (outputs) ----------------------------------
static constexpr uint PIN_A_DATA = 2;  // serial audio sample (I2S, MSB-first)
static constexpr uint PIN_A_SUBQ = 1;  // subcode Q data stream (the CPLD makes the clocks)
static constexpr uint PIN_A_EMPH = 0;  // de-emphasis flag (per track)
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

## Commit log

2026-09-06 beta version Kicad project and gerber
    [MatshitaPico-B_Cu.gbr, MatshitaPico-B_Mask.gbr, MatshitaPico-B_Paste.gbr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]
2026-10-08 mpdisk.device and bootcd mpmount
